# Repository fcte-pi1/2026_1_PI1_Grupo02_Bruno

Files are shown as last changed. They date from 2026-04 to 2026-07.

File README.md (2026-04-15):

# Template PI1

Esse é o _template_ de repositório para ser utilizado pelos grupos de PI1 para organizar seu projeto. O _template_ é dividido em pastas, onde cada parte do projeto deve ser armazenada. Os arquivos a serem armazenados incluem documentação, código-fonte, arquivos de CAD, esquemáticos, arquivos de simulação de circuitos, e dados.

A organização e a correta utilização do repositório do projeto serão considerados na avaliação do grupo. Dessa forma, recomenda-se que *todos os membros* do grupo leiam as instruções deste repositório, aprendam a a utilizar o git (caso ainda não saibam) e também que o grupo combine uma estratégia de como irão utilizar o repositório em conjunto. Dessa forma não deixem de utilizar todas as ferramentas que o GitHub oferece, incluindo branchs, PRs, revisões, issues, calendários, dentre outros.

Lembrem sempre de evitar enviar arquivos muito grandes (>5MB). No caso de vídeos e outros arquivos pesados que são necessários, armazenar o arquivo em outra plataforma e colocar aqui apenas o _link_.

> [!IMPORTANT]
> A estrutura de pastas do projeto não reflete a divisão de equipes. Os membros podem e devem trabalhar nas diferentes pastas a depender da necessidade do projeto.

## Utilização

1. Crie o repositório do projeto utilizando a nomenclatura padrão no formato: `<ano>.<semestre>_PI1_Grupo<n>_<professor>`. Como um exemplo, um nome formado corretamente seria `2026.1_PI1_Grupo1_Diogo`. 

2. Crie uma equipe do projeto com a mesma nomenclatura do repositório porém com o sufixo `_Equipe`, como `2026.1_PI1_Grupo1_Diogo_Equipe`, e solicite, caso necessário, que a equipe tenha permissão de escrita no repositório do projeto.

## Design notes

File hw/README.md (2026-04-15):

# _Hardware_

Esta pasta deverá armazenar arquivos referentes a:

- Simulações de circuitos eletrônicos (alimentação, sensores, atuadores etc.): [Qucs](https://qucs.sourceforge.net/), [QSPICE](https://www.qorvo.com/design-hub/design-tools/interactive/qspice), [Fritzing](https://fritzing.org/), dentre outros.
- Esquemáticos de circuitos: [KiCad](https://www.kicad.org/), Qucs, QSPICE.
- Diagramas de bloco: [Canva](https://www.canva.com/pt_br/), [TikZ](https://tikz.net/).
- _Datasheets_ de componentes eletrônicos, microcontroladores, _shields_ Arduino, motores etc.
- Testes tabelados de circuitos: arquivos CSV, Excel.
- Imagens PNG e JPEG de resultados práticos: fotos de testes reais, gráficos de resultados etc.
- Outros arquivos referentes ao _hardware_ do projeto.

> [!WARNING]
> **Não acrescente código-fonte a esta pasta.** O código desenvolvido para microcontroladores e SOCs ([Arduino](https://www.arduino.cc/), [ESP32](https://www.espressif.com/), [Raspberry Pi](https://www.raspberrypi.com/)) deverá ser armazenado na pasta [src/firmware](https://github.com/fcte-pi1/template/tree/main/src/firmware) deste repositório.

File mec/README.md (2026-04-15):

# _Mecânica e Estruturas_

Esta pasta deverá ser utilizada para armazenar arquivos relativos ao projeto estrutural, mecanismos, materiais, estudos aerodinâmicos, equações dinâmicas, construção e manufatura, impressão 3D, e correlatos.

Os arquivos a serem incluídos, são, dentre outros:
- Arquivos CAD de peças e montagens (FCStd, STEP, etc). 
- Desenhos técnicos (pdf, etc).
- Arquivos de impressão 3D (STL, etc).
- Imagens rasterizadas e vetorizadas (eps, pdf, svg, etc).
- Documentos e estudos realizados para o projeto (markdown, LaTeX, etc).

Durante o projeto, os grupos são encorajados a realizarem estudos para o projeto de estruturas, mecanismos, aerodinamica, dentre outros, e muitos desses estudos não caberão no relatório a ser entregue. Esses estudos podem ser colocados também nessa pasta, preferencialmente utilizando markdown (.md) para facilitar a leitura em ambiente web. Lembre-se que você pode utilizar equações em formato LaTeX no markdown e não deixe de utilizar links para o material de referencia que utilizaram. Estudos bem realizados contarão de maneira positiva na avaliação das equipes, porém lembre-se que não é permitida a utilização de IA, e que esse material deve ser principalmente útil à equipe.

> [!WARNING]
> Não acrecente arquivos da parte de hardware eletrônico aqui, como arquivos de KiCAD. Estes devem ser salvos na pasta [hw](https://github.com/fcte-pi1/template/tree/main/hw) deste repositório.

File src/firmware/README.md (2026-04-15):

# _Firmware_
Esta pasta deverá armazenar arquivos referentes a:

- Código-fonte para microcontroladores e SOCs: [Arduino](https://www.arduino.cc/), [ESP32](https://www.espressif.com/), [Raspberry Pi](https://www.raspberrypi.com/), dentre outros.
- Projetos de organização destes códigos, caso utilize IDEs: [Arduino IDE](https://www.arduino.cc/en/software/), [Visual Studio](https://visualstudio.microsoft.com/pt-br/downloads/) etc.
- Arquivos de configuração: ```CMakeLists.txt``` se for usar [CMake](https://cmake.org/download/), ```Makefile``` se for usar [make](https://www.cs.colby.edu/maxwell/courses/tutorials/maketutor/) etc.

Evite incluir:
- Artefatos de compilação: os arquivos de saída compilados (binários, arquivos objeto, .hex, .elf) devem ser gerados pelo processo de compilação e não incluídos no repositório.
- Arquivos temporários/específicos do sistema operacional: Arquivos como .DS_Store (macOS) ou arquivos de configuração do editor (a menos que esteja usando uma configuração compartilhada como .editorconfig).
- Configurações pessoais: Arquivos de configuração locais específicos da máquina do desenvolvedor.

> [!WARNING]
> **Não acrescente arquivos referentes a _hardware_ nesta pasta.** Eles deverão ser armazenados na pasta [hw](https://github.com/fcte-pi1/template/tree/main/hw) deste repositório.

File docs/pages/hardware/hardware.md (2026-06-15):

# Descrição de Hardware

O núcleo de hardware do projeto RataTuring é responsável pela **percepção do ambiente**, **controle de movimentação** e **transmissão de telemetria** em tempo real. Para atender aos requisitos do Micromouse, foram selecionados componentes capazes de oferecer processamento eficiente, leitura precisa do ambiente e controle confiável dos atuadores.

## 1. Microcontrolador

A unidade central de controle do robô é a **ESP32 WROOM-32E de 38 pinos**, escolhida por oferecer quantidade suficiente de portas GPIO *(General Purpose Input/Output)* para integração simultânea com encoders magnéticos, sensores infravermelhos e chave DIP de configuração.

Além da maior disponibilidade de interfaces físicas, a ESP32 atende às necessidades computacionais do projeto ao oferecer arquitetura de **32 bits**, frequência de operação de até **240 MHz**, conectividade **Wi‑Fi e Bluetooth integradas** e suporte à execução paralela por meio de **dois núcleos de processamento**.

Essa arquitetura permite que o robô execute simultaneamente tarefas como processamento de sensores, controle de movimentação, mapeamento do labirinto e transmissão de telemetria em tempo real para o sistema web.

A utilização da versão de 38 pinos também demandou um planejamento cuidadoso do mapeamento das GPIOs, especialmente devido à presença de portas associadas à memória flash interna do chip, garantindo estabilidade no funcionamento do sistema embarcado.

## 2. Sensores de Percepção

Para a detecção de paredes e leitura do ambiente, foram selecionados **sensores infravermelhos (IR)**. Essa escolha foi motivada pela baixa latência de leitura e pela adequação ao ambiente controlado do Micromouse, onde as superfícies do labirinto possuem características visuais padronizadas.

Os sensores IR permitem detectar obstáculos por meio da emissão e reflexão de luz infravermelha, possibilitando a estimativa da distância até paredes próximas. Foram definidos **três sensores** reflexivos TCRT5000, posicionados à esquerda, à frente e à direita do robô.

## 3. Sistema de Locomoção e Odometria

O sistema de movimentação utiliza **motores DC N20 com encoders magnéticos integrados**, responsáveis tanto pela propulsão quanto pela medição do deslocamento do robô.

Os encoders geram pulsos elétricos proporcionais à rotação do eixo do motor, permitindo ao microcontrolador calcular com precisão a **distância percorrida** e a **velocidade das rodas**. Essas informações são fundamentais para o rastreamento da posição do robô no labirinto, especialmente em trechos onde os sensores infravermelhos não conseguem fornecer referências suficientes do ambiente.

Assim, os encoders complementam o sistema de percepção, fornecendo dados essenciais para o mapeamento e navegação.

## 4. Sistema de Alimentação

O robô é alimentado por uma **bateria LiPo de 7,4 V**, cuja tensão é superior à suportada pela ESP32. Para adequar a alimentação do sistema, optou-se pela utilização de um **conversor DC-DC Step-Down (Buck Converter LM2596)**.

A escolha do conversor buck ocorreu devido à sua **alta eficiência energética**, reduzindo a tensão da bateria sem dissipar grande parte da energia em forma de calor, diferentemente de reguladores lineares ou divisores resistivos. Essa característica contribui para maior autonomia energética do robô e maior estabilidade operacional durante a execução da corrida.

Além disso, para atender ao requisito de monitoramento energético em tempo real, foi implementado um **circuito divisor de tensão**, permitindo que a ESP32 realize a leitura segura da tensão da bateria e envie essas informações ao sistema de telemetria.

## 5. Controle dos Motores

O acionamento dos motores é realizado por meio da **ponte H TB6612FNG**, responsável por intermediar a comunicação entre a ESP32 e os motores DC.

Esse componente foi escolhido em substituição ao modelo L298N devido ao **menor tamanho físico**, **menor resistência interna** e **maior eficiência energética**, resultando em maior estabilidade de tensão e melhor desempenho no controle dos motores.

Além disso, a TB6612FNG suporta frequências elevadas de controle PWM, permitindo ajustes mais precisos de velocidade e reduzindo vibrações ou perda de torque em baixas velocidades, aspecto essencial para a navegação precisa em um labirinto Micromouse.

## 6. Considerações Gerais

A arquitetura de hardware proposta foi definida de forma a atender aos requisitos funcionais do projeto, principalmente aqueles relacionados à **navegação autônoma**, **mapeamento do labirinto**, **precisão de movimento** e **transmissão de telemetria em tempo real**. A combinação entre ESP32, sensores IR, encoders, conversor buck e ponte H fornece uma base robusta para o funcionamento do sistema embarcado do RataTuring.

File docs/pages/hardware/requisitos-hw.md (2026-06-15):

# Requisitos de Hardware

| Código | Descrição |
| --- | --- |
| **RF-ELEC-01**  | **Redução e Estabilização de Tensão para a Lógica:** Medição estável de **3.3V (±0.1V)** nos terminais de saída do módulo. |
| **RF-ELEC-02**  | **Monitoramento de Tensão da Bateria via ADC:** O Serial Monitor do ESP32 deve exibir a voltagem real da bateria com margem de erro de **±0.2V**. |
| **RF-ELEC-03**  | **Interface de Segurança e Proteção de Polaridade:** O sistema deve ligar/desligar via chave física e bloquear a passagem de energia se a bateria for conectada invertida. |
| **RF-ELEC-04**  | **Detecção de Barreiras Físicas via Infravermelho (IR):** O hardware deve gerar uma variação de tensão entre **0V e 3.3V** proporcional à distância da parede. |
| **RF-ELEC-05**  | **Mapeamento da Curva de Resposta dos Sensores:** O firmware deve converter os valores do ADC (**0–4095**) em distância linear (**cm**) com precisão de **±1 cm** na faixa de **3 cm a 15 cm**. |
| **RF-ELEC-06**  | **Definição e Mapeamento de Pinos (Pinout) do ESP32:** Conexão física de todos os periféricos (sensores e motores) sem conflitos de GPIOs ou funções especiais. |
| **RF-ELEC-07**  | **Controle de Direção e Potência dos Motores:** Acionamento bi-direcional das rodas utilizando a tensão da bateria sob comando lógico do ESP32. |
| **RF-ELEC-08**  | **Modulação de Velocidade por Largura de Pulso (PWM):** Variação linear da rotação dos motores controlada pelo software entre **10% e 100%** da potência. |
| **RNF-ELEC-01** | **Filtragem de Interferência Eletromagnética (EMI):** A leitura do sensor no Serial Monitor não deve oscilar mais que **2%** quando os motores estiverem em carga máxima. |

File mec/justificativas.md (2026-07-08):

# Núcleo de Estruturas & Mecânica — Micromouse

Este documento detalha o desenvolvimento mecânico, os requisitos de projeto, a seleção de materiais e o processo de montagem tanto do chassi do robô quanto do labirinto de testes, enfatizando o caráter multidisciplinar integrado à eletrônica e alimentação.

---

## Abordagem Multidisciplinar & Requisitos de Design

O design mecânico do Micromouse foi inteiramente concebido sob a ótica da **multidisciplinaridade**. O chassi não atua apenas como suporte físico, mas sim como uma interface otimizada para acomodar de forma compacta e estratégica os subsistemas das outras áreas:

* **Arquitetura em Dois Andares:** * **Primeiro Andar (Inferior):** Dedicado exclusivamente à acomodação dos componentes de alimentação e potência (baterias e fiação pesada), rebaixando o centro de gravidade.
    * **Segundo Andar (Superior):** Dedicado à proteção e fixação das placas de circuito, sensores e hardware de processamento.
* **Locomoção e Manobrabilidade:** Utiliza um sistema de direção diferencial com **2 motores N20 individuais e independentes** (um para cada roda) e **1 roda boba (*caster*)** posicionada na parte frontal. Essa configuração permite que o robô gire em torno do seu próprio eixo, economizando tempo e espaço.
* **Restrição Geométrica:** O robô foi projetado para caber perfeitamente e se mover de forma fluida dentro de uma única célula do labirinto (**18x18 cm**), garantindo folga nas curvas e evitando colisões com as paredes.

---

## Especificações Técnicas e Dimensões

### O Chassi
* **Material:** Impressão 3D (Polímero).
* **Dimensões Gerais:** 100 mm de comprimento × 70 mm de largura.
* **Pilares de Sustentação:** 16 mm de altura (espaçamento entre os andares).
* **Rodas:** 43 mm de diâmetro × 18 mm de largura.

### O Labirinto (Concepção Modular)
O labirinto de testes adota uma filosofia de **modularidade** para montagem e desmontagem rápida, crucial para os testes práticos da equipe de software. Ele foi projetado para mitigar interferências nos sensores ópticos e de distância do robô:
* **Dimensões da Base Principal:** 795 × 795 mm.
* **Malha da Base:** Matriz contendo **25 furos** para acoplamento dinâmico.
* **Células:** Padrão de 18 × 18 cm cada.
* **Paredes e Pilares:** 6 cm de altura.
* **Materiais e Acabamento Visual (Requisito Sensorial):**
    * **Base:** Feita em MDF com pintura em **preto fosco**, evitando reflexos ópticos indesejados que comprometeriam a leitura dos sensores de linha/distância.
    * **Paredes:** Feitas em MDF com acabamento em **branco** e o **topo em vermelho**, garantindo o contraste necessário para a navegação do robô.
    * **Pilares de Encaixe:** Impressos em 3D para acoplamento firme na base.

---

## Processo de Montagem

### Montagem do Robô:
1.  **Fixação dos Motores:** Os dois motores N20 são posicionados no primeiro andar e firmados utilizando **clamps parafusados**, o que elimina folgas mecânicas e garante rigidez durante acelerações bruscas.
2.  **Acoplamento das Rodas:** As rodas principais são conectadas diretamente aos eixos dos motores N20 e a roda boba é posicionada na seção frontal inferior.
3.  **União dos Andares:** O segundo andar é fixado sobre o primeiro utilizando os pilares de sustentação de 16 mm.

### Montagem do Labirinto:
1.  As paredes de MDF possuem um design com **extremidades dentadas**.
2.  Esses dentes se acoplam diretamente aos **pilares de encaixe em 3D**.
3.  O conjunto (parede + pilar) é encaixado por pressão na **matriz de 25 furos** da base de MDF preta, permitindo alterar a configuração do labirinto facilmente entre as sessões de teste.

---

## Análise Estrutural Computacional (ANSYS)

Para garantir a confiabilidade do robô antes da fabricação dos componentes físicos, o modelo tridimensional do chassi foi submetido a uma **Análise Estrutural Numérica no software ANSYS**. 
O estudo focou na simulação estática e dinâmica para verificar o comportamento do polímero impresso sob a ação das cargas reais do projeto (peso das baterias, placas eletrotécnicas, forças de aceleração e frenagem dos motores N20). A análise validou que a espessura das paredes e a disposição dos pilares de 16 mm suportam os esforços operacionais com margem de segurança adequada, evitando trincas ou deformações excessivas durante as manobras.

---

## Localização dos Arquivos no Repositório

Toda a modelagem 3D (arquivos `.CATPart`), simulações, arquivos de impressão e detalhamentos estão centralizados na pasta de mecânica do projeto:

```text
📂 Mec/
├── 📂 CAD Labirinto/           # Modelagem tridimensional do labirinto modular em CATIA
├── 📂 Desenho Técnico/         # Desenhos técnicos detalhados com as cotas e dimensões formais
├── 📂 Robô/                    # Modelos finais do chassi (CATPart), análises estruturais (ANSYS) e Resultados.
└── 📂 STL para impressão 3D/   # Arquivos de impressão (STL)

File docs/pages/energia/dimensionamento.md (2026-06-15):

# Dimensionamento Energético

## 1. Introdução

Dimensionar e implementar um sistema de alimentação que garanta uma autonomia mínima de 30 minutos de operação contínua, utilizando baterias que possam ser recarregadas totalmente em menos de duas horas.

---

## 2. Levantamento de Carga (Especificação dos Componentes)

A Tabela 1 detalha todos os componentes eletrônicos e eletromecânicos integrados ao robô, seus respectivos consumos nominais de corrente, tensões de operação e estimativa de energia consumida.

### Tabela 1: Especificação de consumo dos componentes do Micromouse

| Componente | Especificação | Quantidade | Corrente (mA) | Tensão | Energia (J) |
| :--- | :--- | :---: | :---: | :---: | :---: |
| Microcontrolador | ESP32 WROOM 32E | 1 | 117 (com WiFi) | 3.3V | 695,16 |
| Buck Converter | LM2596 | 1 | 21 | 7.4V | 279,72 |
| Sensores IR | TCRT5000 | 3 | 20 | 3.3V | 356,40 |
| Ponte H | TB6612FNG | 1 | 5 | 3.3V | 29,70 |
| Motor N20 - A | | 1 | 53 | 6V | 572,40 |
| Motor N20 - B | | 1 | 46 | 6V | 496,80 |

---

## 3. Cálculo da Corrente Total ($I_{total}$)

Para determinar o consumo total no pior cenário operacional (todos os componentes atuando simultaneamente e em carga máxima), aplica-se a seguinte equação de soma das correntes:

$$I_{total} = I_{esp32\_wifi} + I_{buck} + (3 \times I_{ir}) + I_{ponteH} + I_{motorA} + I_{motorB}$$

Substituindo os valores nominais fornecidos pelo relatório técnico:

$$I_{total} = 117\text{ mA} + 21\text{ mA} + (3 \times 20\text{ mA}) + 5\text{ mA} + 53\text{ mA} + 46\text{ mA}$$
$$I_{total} = 117 + 21 + 60 + 5 + 53 + 46$$
$$I_{total} = 242\text{ mA}$$

---

## 4. Cálculo de Autonomia do Sistema

Para a validação real do comportamento elétrico no solo (labirinto), adota-se uma margem de segurança severa com fator de correção de $2\times$ sobre o consumo medido em vazio, resultando em uma taxa de queda projetada de $0,96\text{ V/h}$. O tempo de uso contínuo estimado ($T_{autonomia}$) considerando a janela útil de tensão de $2,4\text{ V}$ da bateria é calculado por:

$$T_{autonomia} = \frac{2,4\text{ V}}{0,96\text{ V/h}}$$

$$T_{autonomia} \approx \mathbf{2,5\text{ horas}}$$

Convertendo o tempo estimado para minutos:

$$T_{autonomia} = 2,5 \times 60 = \mathbf{150\text{ minutos}}$$

---

## 5. Conclusão

Com o consumo total de **242 mA**, é estimado para o arranjo de baterias de 1200 mAh uma autonomia de aproximadamente **150 minutos** (cerca de 2 horas e meia) de funcionamento contínuo pro micromouse. Considerando também que a bateria escolhida é recarregável e pode ser recarregada completamente em um período de até duas horas.

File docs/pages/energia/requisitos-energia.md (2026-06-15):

# Requisitos de Energia
| Código | Descrição |
|---|---|
| **RF-ENER-01** | A fonte de energia deve ser altamente compacta e apresentar uma excelente relação peso/potência, garantindo que o chassi permaneça leve. |
| **RF-ENER-02** | O sistema de alimentação deve utilizar baterias adequadas para suprir a demanda por um período contínuo de 20 a 30 minutos em regime de testes. |
| **RF-ENER-03** | O conjunto de baterias deve garantir energia suficiente para os componentes e sustentar os picos elétricos do arranque dos motores. |
| **RF-ENER-04** | O projeto deve integrar um BMS como interface de proteção contra descarga profunda, sobrecarga e curtos-circuitos. |

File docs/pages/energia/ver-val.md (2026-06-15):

# Relatório de Testes de Verificação e Validação: Consumo Energético

## 1. Objetivo

Avaliar o perfil de descarga da alimentação do micromouse sob diferentes regimes de operação.

O sistema utiliza uma bateria composta por 2 células de 3,7 V ligadas em série, resultando em uma tensão nominal de 7,4 V e capacidade de 1200 mAh. O intuito é estimar a autonomia do projeto e garantir que a carga suporte a conclusão do labirinto sem interrupções por queda de tensão durante as avaliações da disciplina.

---

## 2. Metodologia de Verificação (Ensaios em Bancada)

Para mapear o consumo de energia dos diferentes subsistemas, a queda de tensão da bateria foi monitorada via multímetro durante dois ensaios práticos, com duração de 1 hora cada.

### 2.1 Teste 1 – Sistema Lógico em Standby (Perfil Quiescente)

Apenas o microcontrolador (ESP32) e o circuito regulador (Buck Converter) foram mantidos ativos, sem acionamento dos motores.

**Resultado:** Queda de 0,16 V/h.

**Análise:** Consumo mínimo e estável, demonstrando alta eficiência da eletrônica de controle e do regulador chaveado quando não há demanda de potência.

### 2.2 Teste 2 – Atuadores em Vazio (Perfil Dinâmico)

Sistema lógico ativo (com comunicação Wi‑Fi) em conjunto com o acionamento dos motores em velocidade máxima, porém com o robô suspenso em bancada (rodas girando no ar, sem contato com o solo).

**Resultado:** Queda de 0,48 V/h.

**Análise:** O dreno de energia triplicou em relação ao estado de repouso (3×), confirmando que a carga motriz é a variável dominante no consumo do sistema.

---

## 3. Medição de Corrente e Comparação Teórico-Prática

### 3.1 Mapeamento de Corrente (Ensaios Isolados)

- **Sistema Lógico (Sem Wi‑Fi):** 83 mA (ESP) + 21 mA (Buck) = 104 mA
- **Sistema Lógico (Com Wi‑Fi):** 117 mA (ESP) + 21 mA (Buck) = 138 mA
- **Sistema de Tração (Vazio):** 53 mA (Motor A) + 46 mA (Motor B) + 5 mA (Ponte H) = 104 mA

Corrente total de pico:

```text
Itotal = 138 mA + 104 mA = 242 mA
```

### 3.2 Modelagem Teórica vs. Medição Empírica

Considerando a capacidade nominal da bateria de 1200 mAh:

```text
Tempo Teórico = 1200 mAh / 242 mA ≈ 4,95 horas
```

Janela útil de tensão da bateria:

```text
8,4 V - 6,0 V = 2,4 V
```

Taxa teórica esperada:

```text
Taxa Teórica = 2,4 V / 4,95 h ≈ 0,484 V/h
```

| Comparação | Valor |
|---|---|
| Modelo Matemático | 0,484 V/h |
| Teste Prático | 0,480 V/h |

### 3.3 Potência e Consumo Energético Total

```text
Ptotal = 7,4 V × 0,242 A ≈ 1,79 W
```

Energia disponível:

```text
E = 8,88 Wh
```

Autonomia energética:

```text
Tempo Teórico = 8,88 Wh / 1,79 W ≈ 4,95 horas
```

**Conclusão da comparação:** O ensaio prático validou o modelo matemático de consumo. A variação registrada é explicada pela incerteza natural do equipamento de medição. O consumo global inferior a 2 W confirma a adequação energética do hardware.

---

## 4. Validação e Projeções para a Apresentação Final

Os dados obtidos em bancada verificam o comportamento elétrico isolado do hardware.

Contudo, para a validação real no labirinto, deve-se considerar que o Teste 2 representa um cenário otimista (rodas livres de atrito).

No chão, os motores demandarão maior corrente elétrica para vencer a inércia, deslocar a massa total do robô e superar o atrito da superfície. Esse esforço mecânico adicional exigirá mais torque, acelerando a taxa de descarga em relação aos 0,48 V/h medidos no ar.

---

## 5. Análise de Atendimento das Demandas Energéticas

### 5.1 Demanda de Autonomia Mínima

O robô necessita de autonomia suficiente para realizar múltiplas tentativas de resolução do labirinto durante a avaliação oficial da disciplina, sem necessidade de recargas constantes.

### 5.2 Margem de Segurança Aplicada

Considerando um cenário real severo com o dobro do consumo aferido no ar:

```text
0,96 V/h = 2 × 0,48 V/h
```

Autonomia estimada:

```text
Autonomia = 2,4 V / 0,96 V/h ≈ 2,5 horas (150 minutos)
```

### 5.3 Status de Atendimento

Os testes documentam que o arranjo de baterias escolhido (1200 mAh, 2S) atende com ampla folga térmica e elétrica às necessidades do projeto, mitigando riscos de reinicialização do microcontrolador por subtensão.

---

## 6. Conclusão

Os ensaios em bancada cumpriram os requisitos de verificação energética.

O mapeamento do consumo permitiu estabelecer um limite inferior confiável de descarga e calcular o tempo de persistência em operação.

Com uma autonomia projetada superior a 2 horas em regime de esforço mecânico, a integridade elétrica do micromouse está validada para a apresentação final da disciplina.

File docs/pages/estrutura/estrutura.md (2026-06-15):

# Estruturas: Chassi e Labirinto

## 1. Visão Geral do Projeto

O chassi e o labirinto do Micromouse foram modelados no CATIA, priorizando **compactação, estabilidade, modularidade e desempenho em navegação autônoma**.

O chassi foi desenvolvido com **direção diferencial**, utilizando duas rodas de tração independentes, permitindo curvas rápidas e rotações no próprio eixo. Já o labirinto foi projetado de forma **modular**, facilitando montagem, desmontagem e criação de diferentes cenários de teste.

---

## 2. Escolha dos Materiais

Após análise comparativa entre acrílico, MDF e impressão 3D, optou-se pela **impressão 3D** para o chassi devido aos seguintes fatores:

### Justificativas principais:

* **Maior liberdade geométrica**, permitindo peças complexas e encaixes específicos;
* **Boa resistência mecânica** para o uso esperado;
* **Baixo custo do material**, especialmente considerando que não haverá cobrança de produção.

---

## 3. Sistema de Locomoção (Rodas)

Foi adotada uma configuração de **duas rodas de tração independentes + roda boba frontal**.

### Justificativas:

* Permite o robô **girar sobre o próprio eixo**;
* Facilita curvas rápidas e precisas;
* Reduz tempo de navegação no labirinto;
* Melhora a eficiência em espaços reduzidos.

Essa arquitetura é amplamente utilizada em robôs Micromouse por oferecer **alta manobrabilidade**.

---

## 4. Chassi

| Característica | Chassi Novo |
| --- | ---: |
| Comprimento | 100 mm |
| Largura | 70 mm |
| Altura dos pilares | 16 mm |

---

## 5. Centro de Gravidade e Momento de Inércia

Foi realizada uma análise física no CATIA para verificar estabilidade.

### Resultado principal:

O **centro de gravidade ficou próximo ao centro geométrico do robô**, indicando **boa distribuição de massa**.

### Benefícios:

* Menor oscilação em curvas;
* Mais estabilidade em aceleração e frenagem;
* Melhor comportamento em mudanças bruscas de direção.

Além disso, houve **redução dos momentos de inércia**, o que significa:

### Impacto prático:

* O robô exige **menos torque dos motores** para girar;
* Faz curvas mais rápidas;
* Tem respostas mais ágeis nas correções de trajetória;
* Melhor desempenho em testes de Micromouse.

A redução da altura dos pilares foi essencial para concentrar a massa mais próxima do plano central do robô.

---

## 6. Projeto do Labirinto

O labirinto foi desenvolvido pensando em **precisão dimensional, modularidade e confiabilidade dos sensores**.

### Estrutura:

* Base em **MDF preto fosco**;
* Pilares produzidos em **impressão 3D**;
* Sistema de encaixe modular;
* Matriz de furos para diferentes configurações do percurso.

### Justificativas importantes:

#### 6.1 Base Preto Fosco

Escolhida para reduzir reflexos de luz.

**Benefício:**
Evita interferência nos sensores do robô, melhorando a leitura das paredes e do solo.

---

#### 6.2 Tolerância de Encaixe

Foi criada uma folga entre furos e pinos (**0,5 mm**).

**Benefício:**

* Facilita montagem;
* Compensa pequenas imperfeições da impressão 3D;
* Evita esforço excessivo e deformações.

---

#### 6.3 Estabilidade Mecânica

A espessura da estrutura foi escolhida para evitar vibração das paredes.

**Benefício:**
Evita erros de mapeamento do robô durante deslocamentos rápidos.

---

#### 6.4 Modularidade

O sistema permite **alterar rapidamente a configuração do labirinto**.

**Benefícios:**

* Criar vários cenários de teste;
* Validar o algoritmo BFS;
* Repetir experimentos com diferentes layouts.

Furos não utilizados serão nivelados com peças impressas em 3D para evitar irregularidades no piso e erros de odometria.

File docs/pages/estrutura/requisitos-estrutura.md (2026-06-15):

# Requisitos de Estruturas
| Código | Descrição |
|---|---|
| **RF-LAB-01** | O Labirinto deve ter paredes de 1,2 cm de espessura e 5 cm de altura. |
| **RF-LAB-02** | O Labirinto deve ter tamanho 4x4 células. |
| **RF-LAB-03** | As paredes devem ser brancas no topo e vermelhas/pretas nas laterais. O chão deve ser preto fosco para evitar reflexos indesejados nos sensores ópticos. |
| **RF-ESTR-01** | A estrutura deve garantir que o robô suporte o próprio peso e consiga se mover. |
| **RF-ESTR-02** | O chassi deve suportar a montagem de sensores de forma que não haja interferência estrutural na leitura das paredes do labirinto. |
| **RF-ESTR-03** | A estrutura deve garantir que as rodas mantenham contato constante ao solo. |
| **RF-ESTR-04** | O robô deve estar contido em um quadrado de 16 cm × 16 cm. |
| **RNF-ESTR-01** | O material deve ser de baixo custo, resistente e de fácil fabricação. |

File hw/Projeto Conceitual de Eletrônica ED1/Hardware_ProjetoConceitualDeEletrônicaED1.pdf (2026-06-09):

# 4.3 Hardware

A parte que forma o núcleo de Hardware no projeto do Micromouse é relacionado à percepção do mundo e controle de suas ações.
Foi escolhido para atuar como sistema central do robô o microcontrolador ESP32 DevKit V1. Inicialmente, houve dúvida entre ele e o Arduíno Leonardo, porém optou-se por aquele pela sua capacidade de operar com frequências maiores (240MHz) e trabalho com 32 bits. Logo, é possível realizar mais operações se comparado ao Arduino em questão, que trabalha em (16 MHz) e 8 bits. Afinal, essas métricas afetam diretamente a capacidade do microcontrolador fazer cálculos complexos, enquanto o Arduino vai de 0 a 255 por vez, a ESP32 DevKit V1 processa palavras de 32 bits em um clock, assim, o código irá ser executado com uma rapidez consideravelmente maior, característica que se mostra fundamental no requisito que demanda a transmissão de dados de telemetria em tempo real via Wi-fi para um sistema web.
Além disso, o Micromouse precisa simultaneamente: enviar dados de telemetria pro sistema web e comunicar com os demais componentes, recebendo e enviando comandos para eles. Com isso em mente, a ESP32 DevKit V1 tem dois núcleos, o Application CPU e o Protocol CPU, este tem como função transmitir as informações para o website e aquele cuidar das demandas do mundo real. Em decorrer disso, a ESP32 DevKit V1 é capaz de separar as tarefas e fazê-las ao mesmo tempo e, por esse motivo, deve se mostrar mais adequada perante a necessidade de mapear o labirinto, andar nele e ter Wi-Fi e bluetooth integrados, facilitando a visualização do labirinto e seu mapeamento e evitando travar o funcionamento do próprio Micromouse ao mandar os dados por Wi-fi.
Os sensores têm como objetivo realizar a leitura do ambiente e, após pesquisar a fundo, foi decidido que o sensor infravermelho (IR) será uma opção mais coerente se. Projeto Conceitual do Produto 27 comparada ao sensor laser. Isso se deve ao fato de que o sensor IR tem uma latência menor de dados, assim, ao identificar uma parede, o microcontrolador será avisado o mais rápido possível e terá tempo de reagir adequadamente a essa informação. Além disso, devido ao ambiente de uso do Micromouse ser controlado e o labirinto não possuir variações de cores, o uso do sensor IR não apresenta nenhuma contraindicação. Mas para entender melhor o porquê disso é crucial compreender como o sensor IR funciona: ele atira uma ’luz invisível’ e mede o quanto dessa luz é refletida de volta, desse modo, a monocromacia do labirinto permite que o programa de software possa seguir um padrão de lógica ao medir os valores entregues pelos sensores e se torne possível o cálculo da distância. Com isso, depois de escolhidos, é importante determinar quantos serão utilizados. Após discutir com a equipe de software, foi decidido que serão usados quatro sensores: dois frontais angulados, para ser capaz de identificar curvas de forma antecipada, e dois, para manter-se centralizado nos corredores do labirinto.
Para complementar o sistema de percepção, o RataTuring utiliza motores DC N20 equipados com encoders magnéticos embutidos. Mas por que esses sensores são importantes para o Micromouse? Ao imaginá-lo percorrendo um corredor longo, sem paredes na frente perto o suficiente para a leitura eficaz da luz refletida pelos sensores IR, fica evidente a necessidade de medir a distância percorrida por ele para ser possível mapear quantas células do labirinto passaram. Dessa maneira, os encoders leem a rotação do eixo do motor e geram pulsos elétricos a cada fração de giro, depois, o microcontrolador recebe e contabiliza esses pulsos digitais em tempo real. Assim, essa conversão direta de movimento mecânico em dados digitais permite que o sistema calcule, com alta precisão, a velocidade atual das rodas e a distância exata percorrida, informações essenciais para o mapeamento e o rastreamento da posição do robô no labirinto
O próximo impasse foi como regular o nível de tensão da bateria de Polímero de Lítio (LiPo) que oferece 7.4V. Isso se mostra necessário pois a ESP32 DevKit V1 só suporta 5V como alimentação.
Inicialmente, foi cogitado o uso de dois resistores simples organizados num divisor de tensão para resolver esse problema de maneira simples e barata. Porém, o problema está justamente na matemática do divisor de tensão:

V

out = V
in

·

R
2
R

1+R
2

(4.3)

que só funciona perfeitamente quando nada está consumindo energia daquele fio do meio. Entretanto, o ESP 32 não é um componente passivo, ele é dinâmico. Quando ele está apenas usando o núcleo Application CPU, consome pouca energia (por volta de 40 miliamperes). Mas, no momento em que ele liga o Protocol CPU para enviar a telemetria do trajeto, ele já puxa um pico gigantesco de energia (até 400 miliamperes).
Na prática, quando o ESP 32 puxa essa corrente, ele atua como se fosse um terceiro resistor invisível que muda de valor o tempo todo. Dessa maneira, a voltagem que era 3.3V despenca instantaneamente para 1.5V ou menos. Assim, sem energia suficiente, provavelmente o microcontrolador vai apagar e reiniciar sozinho, ou seja, o micromouse morreria no meio do labirinto.
Em seguida, pensei em um diodo Zener (junto com um resistor) ou um regulador linear tradicional que conseguiriam manter a tensão estável em 3.3V mesmo quando o microcontrolador puxar muita energia. Porém, o problema deles é como eles fazem isso: eles transformam o excesso de energia em forma de calor. No RataTuring, houve o receio de que isso viraria um desastre por estar drenando e desperdiçando o consumo de bateria do Micromouse apenas para gerar calor no chassi do carrinho e fazendo com que a bateria durasse poucos minutos.
Finalmente, foi acertado o uso de um módulo Buck Converter LM2596 para baixar essa energia. Assim, um Buck Converter (ou conversor Step-Down) é uma válvula redutora de pressão inteligente. De maneira que, ao invés de simplesmente frear a energia e transformar o excesso em calor, como um resistor (o que desperdiçaria a bateria do Micromouse muito rápido), ele liga e desliga a energia milhares de vezes por segundo. Logo, isso reduz a voltagem média que sai do outro lado de forma extremamente eficiente, fazendo a bateria durar muito mais tempo.
No âmbito de bateria, o requisito do projeto onde se faz necessário haver a leitura do nível da bateria a todo momento em tempo real, fez crucial a implementação de um circuito divisor de tensão. Ele irá contar com dois resistores organizados de modo para que a ESP 32 consiga ler a voltagem da bateria sem queimar, cumprindo o requisito de enviar esse dado para a telemetria.
Em última instância, foi discutida a necessidade de uma Ponte H para fazer a comunicação entre os sinais da ESP32 DevKit V1 com os motores DC N20. Afinal, dessa maneira, os sinais da ESP32 DevKit V1 irão ser suficientemente ampliados, dado que ela funciona em uma voltagem muito menor do que os motores e, caso eles tentassem se comunicar sem a ponte H, a ESP32 DevKit V1 poderia ser danificada por não ter o sinal suficiente para alimentá-los. Quanto ao modelo, a preferência foi do modelo TB6612FNG ao invés do modelo L298N, pois seu tamanho e sua resistência interna são bem menores. Logo, culminará em maior estabilidade de tensão, desse modo, assegurando confiabilidade maior, suportando frequências de até 100 kHz e permitindo o controle de velocidade sem vibração do motor ou perda de força em baixas velocidades.

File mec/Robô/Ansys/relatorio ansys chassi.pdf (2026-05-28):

# Project

First Saved | Tuesday, May 26, 2026
Last Saved | Wednesday, May 27, 2026
Product Version | 2026 R1
Save Project Before Solution | No
Save Project After Solution | No
Project | Page 1 of 23
file:///C:/Users/Mateus/AppData/Roaming/Ansys/v261/Mechanical_Report/Mechanical_Report.htm | 28/05/2026

Project | Page 2 of 23

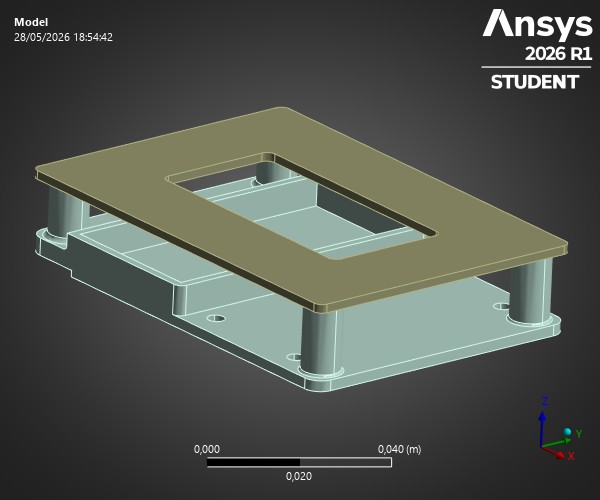
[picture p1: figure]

# Contents

l Units

l Model (A4)
¡ Geometry Imports
n Geometry Import (A3)
¡ Geometry
n Parts
¡ Materials
¡ Coordinate Systems
¡ Connections
n Contacts
n Contact Region
¡ Mesh
¡ Static Structural (A5)
n Analysis Settings
n Acceleration
n Loads
n Solution (A6)
n Solution Information
n Results

l Material Data
¡ PLA

# Units

TABLE 1
Unit System | Metric (m, kg, N, s, V, A) Degrees rad/s Celsius
Angle | Degrees
Rotational Velocity | rad/s
Temperature | Celsius
Project | Page 3 of 23

# Model (A4)

TABLE 2
Model (A4) > Geometry Imports

TABLE 3
Model (A4) > Geometry Imports > Geometry Import (A3)
Object Name | Geometry Imports
State | Solved
Object Name | Geometry Import (A3)
State | Solved
Definition
Source | C:\Users\Mateus\OneDrive\Documentos\UnB\4 sem\PI\Chassi\Final chassis\chassis.stp
Type | Step
Basic Geometry Options
Solid Bodies | Yes
Surface Bodies | Yes
Line Bodies | No
Parameters | Independent
Parameter Key | ANS;DS
Attributes | No
Named Selections | No
Material Properties | No
Advanced Geometry Options
Use Associativity | Yes
Coordinate Systems | No
Reader Mode Saves Updated File | No
Use Instances | Yes
Smart CAD Update | Yes
Compare Parts On Update | No
Analysis Type | 3-D
Mixed Import Resolution | None
Import Facet Quality | Source
Clean Bodies On Import | No
Stitch Surfaces On Import | Program Tolerance
Stitch Tolerance | 0,0000001
Decompose Disjoint Geometry | Yes
Project | Page 4 of 23

Enclosure and Symmetry Processing | Yes

## Geometry

TABLE 4
Model (A4) > Geometry
Object Name | Geometry
State | Fully Defined
Definition
Source | C:\Users\Mateus\OneDrive\Documentos\UnB\4 sem\PI\Chassi\Final chassis\chassis.stp
Type | Step
Length Unit | Millimeters
Element Control | Program Controlled
Display Style | Body Color
Bounding Box
Length X | 0,1 m
Length Y | 7,e-002 m
Length Z | 2,05e-002 m
Properties
Volume | 3,4711e-005 m³
Mass | 4,3041e-002 kg
Scale Factor Value | 1,
Statistics
Bodies | 2
Active Bodies | 2
Nodes | 6897
Elements | 3228
Mesh Metric | None
Update Options
Assign Default Material | No
Basic Geometry Options
Solid Bodies | Yes
Surface Bodies | Yes
Line Bodies | No
Parameters | Independent
Parameter Key | ANS;DS
Attributes | No
Project | Page 5 of 23

TABLE 5
Model (A4) > Geometry > Parts
Named Selections | No
Material Properties | No
Advanced Geometry Options
Use Associativity | Yes
Coordinate Systems | No
Reader Mode Saves Updated File | No
Use Instances | Yes
Smart CAD Update | Yes
Compare Parts On Update | No
Analysis Type | 3-D
Mixed Import Resolution | None
Import Facet Quality | Source
Clean Bodies On Import | No
Stitch Surfaces On Import | Program Tolerance
Decompose Disjoint Geometry | Yes
ID_GeometryPrefProcessPhysicsDefinition | No
Enclosure and Symmetry Processing | Yes
Object Name | Part2|PartBody | 1st level|PartBody
State | Meshed
Graphics Properties
Visible | Yes
Transparency | 1
Definition
Suppressed | No
Stiffness Behavior | Flexible
Coordinate System | Default Coordinate System
Reference Temperature | By Environment
Treatment | None
Material
Assignment | PLA
Nonlinear Effects | Yes
Thermal Strain Effects | Yes
Bounding Box
Length X | 0,1 m
Project | Page 6 of 23

TABLE 6
Model (A4) > Materials
Length Y | 7,e-002 m
Length Z | 7,2e-003 m | 1,85e-002 m
| Properties
Volume | 1,0729e-005 m³ | 2,3981e-005 m³
Mass | 1,3304e-002 kg | 2,9737e-002 kg
Centroid X | -5,e-003 m | -8,959e-003 m
Centroid Y | 3,9581e-014 m | 4,5509e-013 m
Centroid Z | 1,939e-002 m | 3,2278e-003 m
Moment of Inertia Ip1 | 7,0995e-006 kg·m² | 1,4703e-005 kg·m²
Moment of Inertia Ip2 | 1,3915e-005 kg·m² | 2,8909e-005 kg·m²
Moment of Inertia Ip3 | 2,0994e-005 kg·m² | 4,2853e-005 kg·m²
Statistics
Nodes | 2115 | 4782
Elements | 925 | 2303
Mesh Metric | None
Object Name | Materials
State | Fully Defined
Statistics
Materials | 2
Material Assignments | 0

## Coordinate Systems

TABLE 7
Model (A4) > Coordinate Systems > Coordinate System
Object Name | Global Coordinate System
State | Fully Defined
Definition
Type | Cartesian
Coordinate System ID | 0,
Origin
Origin X | 0, m
Origin Y | 0, m
Origin Z | 0, m
Project | Page 7 of 23

Directional Vectors
X Axis Data | [ 1, 0, 0, ]
Y Axis Data | [ 0, 1, 0, ]
Z Axis Data | [ 0, 0, 1, ]
Transfer Properties
Source
Read Only | No

## Connections

TABLE 8
Model (A4) > Connections

TABLE 9
Model (A4) > Connections > Contacts
Object Name | Connections
State | Fully Defined
Auto Detection
Generate Automatic Connection On Refresh Yes Transparency
Enabled Yes
Statistics
Contacts | 1
Active Contacts | 1
Joints | 0
Active Joints | 0
Beams | 0
Active Beams | 0
Bearings | 0
Active Bearings | 0
Springs | 0
Active Springs | 0
Body Interactions | 0
Active Body Interactions | 0
Object Name | Contacts
State | Fully Defined
Definition
Project | Page 8 of 23

TABLE 10
Model (A4) > Connections > Contacts > Contact Regions

Connection Type Contact
Scope
Scoping Method | Geometry Selection
Geometry | All Bodies
Auto Detection
Tolerance Type | Slider
Tolerance Slider | 0,
Tolerance Value | 3,0944e-004 m
Use Range | No
Face/Face | Yes
Face-Face Angle Tolerance | 75, °
Face Overlap Tolerance | Off
Cylindrical Faces | Include
Face/Edge | No
Edge/Edge | No
Priority | Include All
Group By | Bodies
Search Across | Bodies
Statistics
Connections | 1
Active Connections | 1
Object Name | Contact Region
State | Fully Defined
Scope
Scoping Method | Geometry Selection
Contact | 17 Faces
Target | 12 Faces
Contact Bodies | Part2|PartBody
Target Bodies | 1st level|PartBody
Protected | No
Definition
Type | Bonded
Scope Mode | Automatic
Behavior | Program Controlled
Project | Page 9 of 23

Trim Contact | Program Controlled
Trim Tolerance | 3,0944e-004 m
Contact APDL Name
Target APDL Name
Suppressed | No
Display
Element Normals | No
Advanced
Formulation | Program Controlled
Small Sliding | Program Controlled
Detection Method | Program Controlled
Penetration Tolerance | Program Controlled
Elastic Slip Tolerance | Program Controlled
Normal Stiffness | Program Controlled
Update Stiffness | Program Controlled
Pinball Region | Program Controlled
Geometric Modification
Contact Geometry Correction | None
Target Geometry Correction | None

## Mesh

TABLE 11
Model (A4) > Mesh
Object Name | Mesh
State | Solved
Display
Display Style Use Geometry Setting Defaults
Physics Preference | Mechanical
Element Order | Program Controlled
Element Size | Default (6,1887e-003 m)
Sizing
Mesh Sizing | Uniform
Bounding Box Diagonal | 0,12377 m
Average Surface Area | 3,1354e-004 m²
Minimum Edge Length | 3,1416e-004 m
Project | Page 10 of 23

# Static Structural (A5)

TABLE 12
Model (A4) > Analysis

Quality
Check Mesh Quality | Yes, Errors
Error Limits | Aggressive Mechanical
Target Element Quality | Default (0,1)
Smoothing | Medium
Mesh Optimization | No
Mesh Metric | None
Inflation
Use Automatic Inflation | None
Inflation Option | Smooth Transition
Transition Ratio | 0,272
Maximum Layers | 5
Growth Rate | 1,2
Inflation Algorithm | Pre
Inflation Element Type | Wedges
View Advanced Options | No
Advanced
Number of CPUs for Parallel Part Meshing | Program Controlled
Straight Sided Elements | No
Rigid Body Behavior | Dimensionally Reduced
Triangle Surface Mesher | Program Controlled
Topology Checking | Yes
Pinch Tolerance | Default (5,5699e-004 m)
Generate Pinch on Refresh | No
Auto-Map Fillets | No
Automatic Methods
Sheet Body Method | Prime Quad Dominant
Sweepable Body Method | Sweep
Statistics
Nodes | 6897
Elements | 3228
Show Detailed Statistics | No
Project | Page 11 of 23

TABLE 13
Model (A4) > Static Structural (A5) > Analysis Settings
Object Name | Static Structural (A5)
State | Solved
Definition
Physics Type | Structural
Analysis Type | Static Structural
Solver Target | Mechanical APDL
Options
Environment Temperature | 22, °C
Generate Input Only | No
Object Name | Analysis Settings
State | Fully Defined
Step Controls
Number Of Steps | 1,
Current Step Number | 1,
Step End Time | 1, s
Auto Time Stepping | Program Controlled
Maximum Iterations Per Substep | Program Controlled
Solver Controls
Solver Type | Program Controlled
Weak Springs | Off
Solver Pivot Checking | Program Controlled
Large Deflection | Off
Inertia Relief | Off
Quasi-Static Solution | Off
Rotordynamics Controls
Coriolis Effect | Off
Restart Controls
Generate Restart Points | Program Controlled
Retain Files After Full Solve | No
Combine Restart Files | Program Controlled
Nonlinear Controls
Newton-Raphson Option | Program Controlled
Force Convergence | Program Controlled
Moment Convergence | Program Controlled
Project | Page 12 of 23

TABLE 14
Model (A4) > Static Structural (A5) > Accelerations
Displacement Convergence | Program Controlled
Rotation Convergence | Program Controlled
Line Search | Program Controlled
Stabilization | Program Controlled
Advanced
Inverse Option | No
Contact Split (DMP) | Program Controlled
Output Controls
Output Selection | None
Stress | Yes
Back Stress | No
Strain | Yes
Contact Data | Yes
Nonlinear Data | No
Nodal Forces | No
Volume and Energy | Yes
Euler Angles | Yes
General Miscellaneous | No
Contact Miscellaneous | No
Store Results At | All Time Points
Result File Options
Result File Compression | Program Controlled
| Analysis Data Management
Solver Files Directory | C:\Users\Mateus\OneDrive\Documentos\UnB\4 sem\PI\Chassi\chassi ansys_files\dp0\SYS\MECH\
Future Analysis | None
Scratch Solver Files Directory
Save MAPDL db | No
Contact Summary | Program Controlled
Delete Unneeded Files | Yes
Nonlinear Solution | No
Solver Units | Active System
Solver Unit System | mks
Object Name | Acceleration
State | Fully Defined
Project | Page 13 of 23

FIGURE 1
Model (A4) > Static Structural (A5) > Acceleration

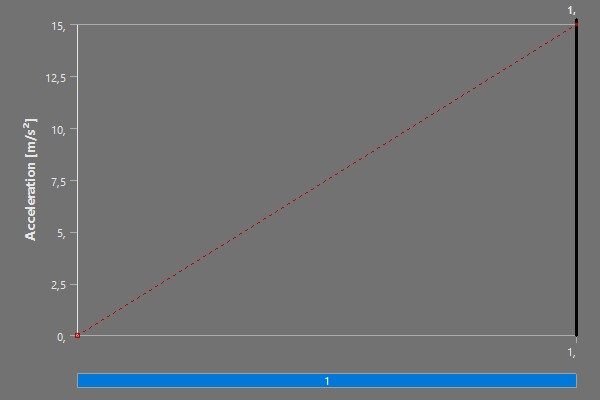
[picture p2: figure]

TABLE 15
Model (A4) > Static Structural (A5) > Loads

Scope
Geometry All Bodies
Definition
Define by | Vector
Magnitude | 15, m/s² (ramped)
Direction | Defined
Suppressed | No
Object Name | Displacement | Fixed Support | Force | Force 2
Project | Page 14 of 23

FIGURE 2
Model (A4) > Static Structural (A5) > Displacement
State | Fully Defined
Scope
Scoping Method | Geometry Selection
Geometry | 2 Faces | 8 Faces | 1 Face
Definition
Type | Displacement | Fixed Support | Force
Define by | Components | | Vector
Coordinate System | Global Coordinate System
X Component | Free
Y Component | Free
Z Component | 0, m (ramped)
Suppressed | No
Applied By | | | Surface Effect
Magnitude | | 0,5635 N (ramped) | 0,98 N (ramped)
Direction | | Defined
Project | Page 15 of 23

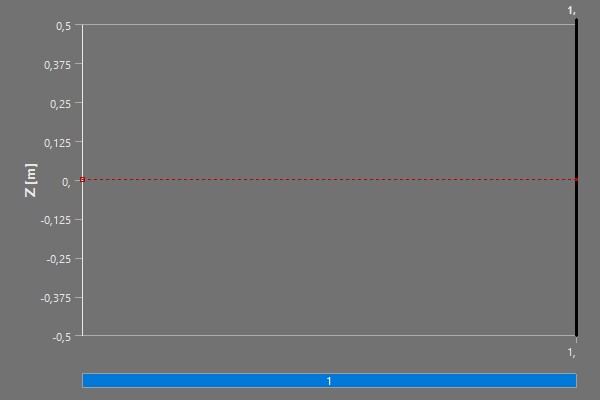
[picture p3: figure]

FIGURE 3
Model (A4) > Static Structural (A5) > Force
Project | Page 16 of 23

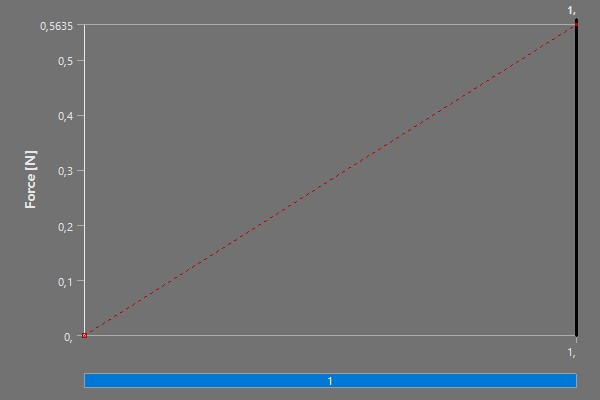
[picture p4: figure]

FIGURE 4
Model (A4) > Static Structural (A5) > Force 2
Project | Page 17 of 23

## Solution (A6)

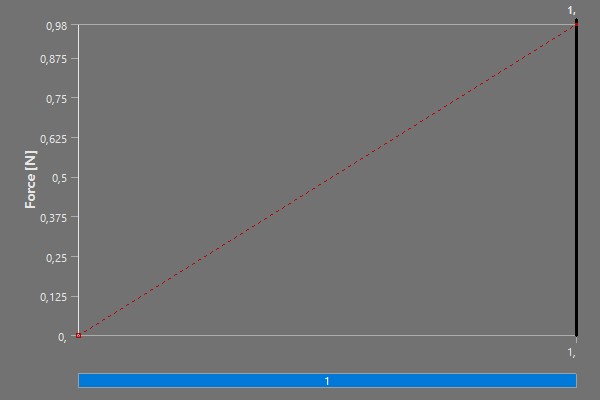
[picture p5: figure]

TABLE 16
Model (A4) > Static Structural (A5) > Solution
Object Name | Solution (A6)
State | Solved
Adaptive Mesh Refinement
Max Refinement Loops | 1,
Refinement Depth | 2,
Information
Status | Done
MAPDL Elapsed Time | 17,205 s
MAPDL Memory Used | 218, MB
Project | Page 18 of 23

TABLE 17
Model (A4) > Static Structural (A5) > Solution (A6) > Solution Information

TABLE 18
Model (A4) > Static Structural (A5) > Solution (A6) > Results

MAPDL Result File Size 2,5 MB Post Processing
Beam Section Results | No
On Demand Stress/Strain | No
Object Name | Solution Information
State | Solved
Solution Information
Solution Output | Solver Output
Newton-Raphson Residuals | 0
Identify Element Violations | 0
Update Interval | 2,5 s
Display Points | All
FE Connection Visibility
Activate Visibility | Yes
Display | All FE Connectors
Draw Connections Attached To | All Nodes
Line Color | Connection Type
Visible on Results | No
Line Thickness | Single
Display Type | Lines
Object Name | Total Deformation | Equivalent Stress
State | Solved
Scope
Scoping Method | Geometry Selection
Geometry | All Bodies
Definition
Type | Total Deformation | Equivalent (von-Mises) Stress
By | Time
Display Time | Last
Separate Data by Entity | No
Calculate Time History | Yes
Project | Page 19 of 23

FIGURE 5
Model (A4) > Static Structural (A5) > Solution (A6) > Total Deformation

Identifier
Suppressed | No
Results
Minimum | 0, m | 16,755 Pa
Maximum | 1,0418e-005 m | 1,6446e+005 Pa
Average | 1,0428e-006 m | 12822 Pa
Minimum Occurs On | 1st level|PartBody
Maximum Occurs On | Part2|PartBody | 1st level|PartBody
Information
Time | 1, s
Load Step | 1
Substep | 1
Iteration Number | 1
Integration Point Results
Display Option | Averaged
Average Across Bodies | No
Project | Page 20 of 23

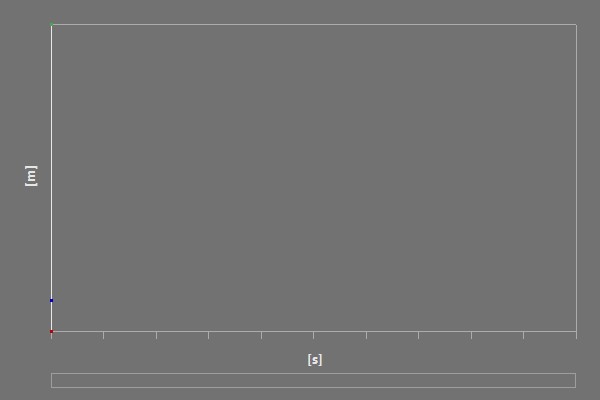
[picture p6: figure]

TABLE 19
Model (A4) > Static Structural (A5) > Solution (A6) > Total Deformation

FIGURE 6
Model (A4) > Static Structural (A5) > Solution (A6) > Equivalent Stress
Time [s] | Minimum [m] | Maximum [m] | Average [m]
1, | 0, | 1,0418e-005 | 1,0428e-006
Project | Page 21 of 23

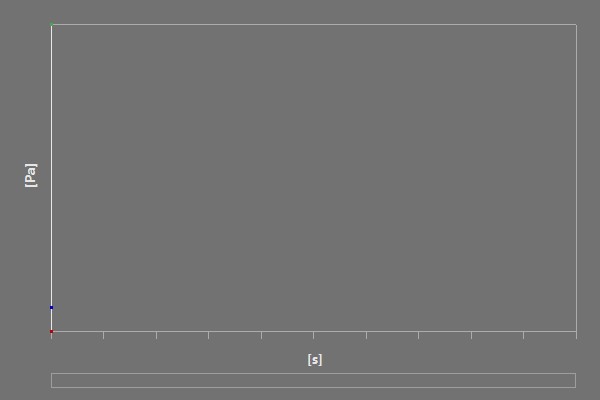
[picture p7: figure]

TABLE 20
Model (A4) > Static Structural (A5) > Solution (A6) > Equivalent Stress

# Material Data

Time [s] | Minimum [Pa] | Maximum [Pa] | Average [Pa]
1, | 16,755 | 1,6446e+005 | 12822

## PLA

TABLE 21
PLA > Constants
Density | 1240, kg m^-3
Project | Page 22 of 23

TABLE 22
PLA > Color

TABLE 23
PLA > Isotropic Elasticity

TABLE 24
PLA > Tensile Yield Strength
Red | Green | Blue
235, | 222, | 222,
Young's Modulus Pa | Poisson's Ratio | Bulk Modulus Pa | Shear Modulus Pa | Temperature C
3,5e+009 | 0,36 | 4,1667e+009 | 1,2868e+009

Tensile Yield Strength Pa
5,e+007
Project | Page 23 of 23

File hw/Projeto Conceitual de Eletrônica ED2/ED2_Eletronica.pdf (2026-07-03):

# 4.3 Hardware

## 4.3.1 Visão Geral

Para esta segunda etapa do projeto, o núcleo de eletrônica consolidou a transição entre o planejamento conceitual de componentes e a implementação física da arquitetura. Assim, o foco desta entrega concentrou-se na segurança lógica no mapeamento de portas, calibração experimental e testes unitários e de integração dos componentes.
Inicialmente, é importante ressaltar que uma mudança de escopo fundamental para o sucesso do projeto foi a substituição do microcontrolador previsto no primeiro ponto de controle. Isso se deu por conta de dois fatores principais: pinos insuficientes e atraso na entrega. O modelo cogitado anteriormente, ESP32 DEVKIT V1, de 30 pinos foi descartado devido a um atraso na postagem da encomenda em decorrência da falta do produto no estoque. Entretanto, isso se mostrou benéfico, pois ficou evidente que essa placa não seria adequada. Assim, foi escolhida a ESP32 WROOM 32E de 38 pinos devido à necessidade de expandir a quantidade de portas GPIO (General Purpose Input/Output) disponíveis. Com o avanço do projeto, a demanda por canais dedicados para encoders magnéticos de alta velocidade, múltiplos sensores infravermelhos e chave DIP ultrapassou o limite físico da placa antiga. Assim, a versão de 38 pinos garantiu a quantidade necessária para o sistema de controle, embora tenha exigido um estudo mais rigoroso de isolamento das trilhas de memória flash integradas ao chip para evitar travamentos indesejados.

## 4.3.2 Sistema de Alimentação

O circuito inicia na bateria de Polímero de Lítio (LiPo) de duas células (2S), cujos terminais físicos foram soldados diretamente nos contatos de leitura e balanceamento (B+,BM e B −) da placa de circuito de proteção BMS (Battery Management System) pelo núcleo de energia. Por sua vez, a saída de carga controlada que alimenta o projeto é extraída exclusivamente dos terminais de potência P + e P − da própria BMS.

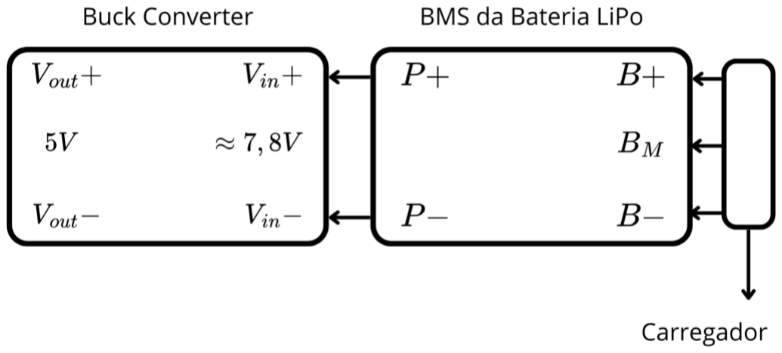
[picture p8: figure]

Figura 1 – Esquemático de Alimentação.

Além disso, a fim de evitar o consumo constante e a descarga parasitária da bateria quando o robô estiver em repouso, foi integrado ao projeto um interruptor geral do tipo chave alavanca SPST (Single Pole Single Throw). Esta chave foi posicionada estrategicamente em série na linha positiva de alta corrente, interceptando o fluxo elétrico entre o terminal P + da BMS e a entrada de tensão positiva (Vin +) do módulo regulador Buck Converter (LM2596). O terminal negativo (P −) conecta-se de forma direta ao barramento comum de terra do conversor (Vin −).

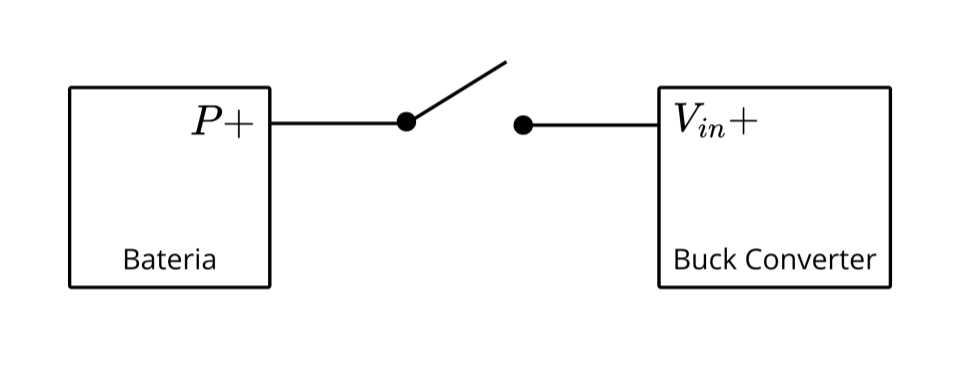
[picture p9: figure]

Figura 2 – Esquemático do Interruptor Geral.

O módulo Buck Converter LM2596 utilizado possui um diferencial técnico muito conveniente para a bancada: um voltímetro digital integrado com um botão seletor físico de alternância. Dessa maneira, ao pressionar este botão, o operador consegue chavear instantaneamente a leitura do display entre a tensão de entrada (vinda da bateria através do P + , variando entre ≈ 6.4V e 8.4V ) e a tensão regulada de saída (ajustada para 5.0V

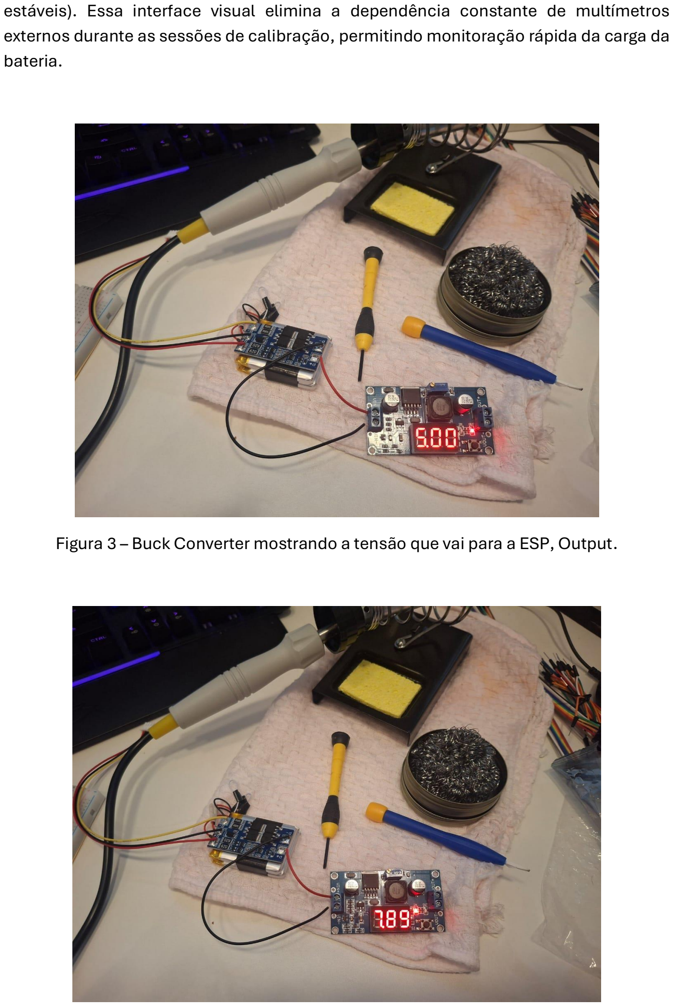
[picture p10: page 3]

estáveis). Essa interface visual elimina a dependência constante de multímetros externos durante as sessões de calibração, permitindo monitoração rápida da carga da bateria.

Figura 3 – Buck Converter mostrando a tensão que vai para a ESP, Output.

Figura 4 – Buck Converter mostrando a tensão da bateria, Input.

## 4.3.3 Mapeamento do microcontrolador

O diagrama de conexões do microcontrolador foi mapeado de forma a blindar o sistema contra falhas de inicialização e perdas de dados sensoriais durante a comunicação sem fio.
Inicialmente, foram mapeados os pinos críticos associados ao barramento de comunicação interna da memória flash do chip e pinos de configuração de boot (Strapping Pins) e todos eles foram permanentemente isolados e marcados como proibidos no projeto. São eles: EN, CLK, SD0, SD1, SD2, SD3, P15, P2, P0, P12, P5, RX e TX. Afinal, conectar qualquer atuador ou sensor a essas linhas poderia forçar a placa a entrar em modos de gravação incorretos durante a energização, impedindo a execução correta do firmware do Micromouse.
Ademais, a arquitetura interna do circuito impresso divide as entradas analógicas em dois blocos: ADC1 e ADC2. Entretanto, há uma restrição física de fábrica na qual o canal ADC2 compartilha o mesmo circuito integrado utilizado pelo rádio Wi-Fi. Consequentemente, no momento em que o RataTuring ativa o protocolo de rede para transmitir dados de telemetria em tempo real para a interface web, todas as leituras de pinos ligados ao ADC2 são congeladas e param de funcionar. Desse modo, a fim de contornar este problema e impedir que o robô fique cego enquanto transmite dados, todas as leituras críticas foram mapeadas exclusivamente no canal ADC1, que opera de forma independente do Wi-Fi. São elas: leitura de carga da bateria e sensores infravermelhos.
Por fim, os 9 pinos GPIOs (General Purpose Input/Output) restantes são classificados como seguros no datasheet do microcontrolador pois possuem estabilidade bidirecional plena. Essa característica permite que atuem tanto como saídas de potência digital confiáveis (acionamento da Ponte H) quanto como entradas de alta velocidade e baixa latência (leitura dos Encoders magnéticos e da Chave DIP de estratégia), assegurando a estabilidade operacional do sistema sem riscos de flutuação lógica ou travamento de boot.

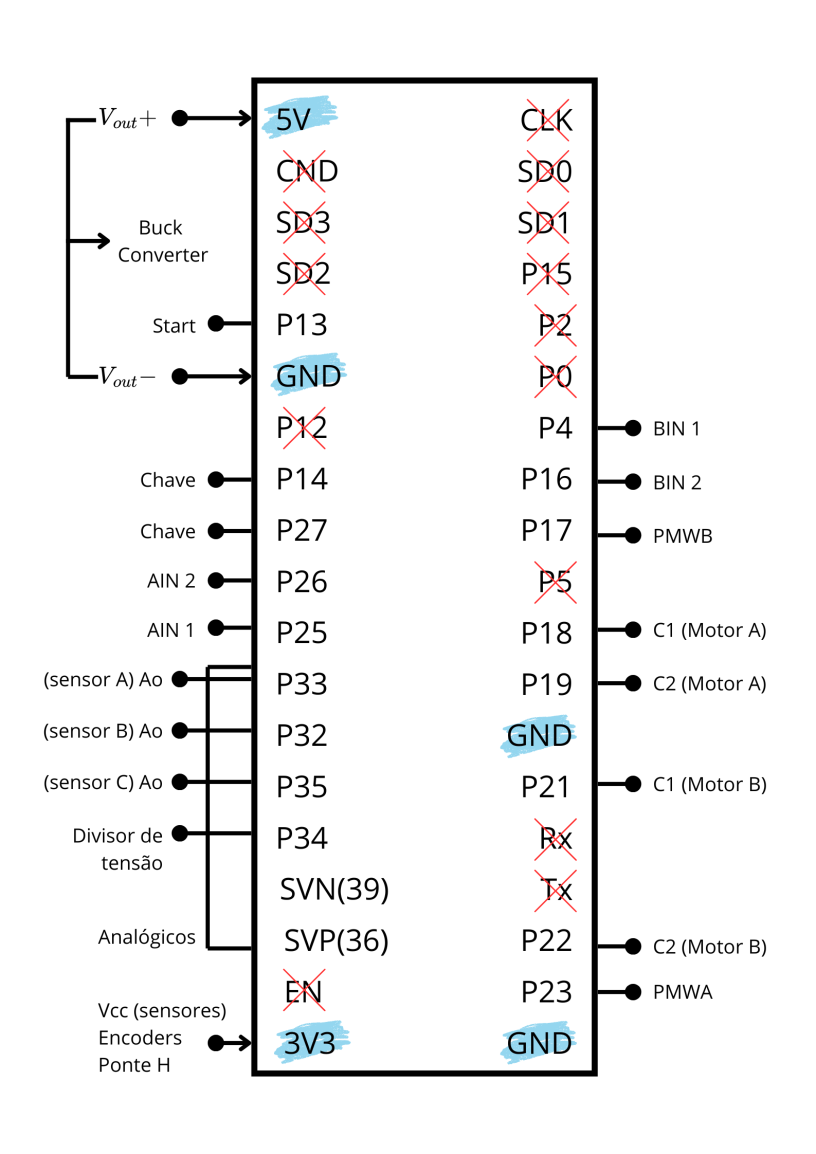
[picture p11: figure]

Figura 5 – Esquemático do mapeamento da ESP

## 4.3.4 Monitoramento da Bateria

Para cumprir o requisito de telemetria em tempo real sem queimar as portas do microcontrolador, foi projetado um circuito divisor de tensão resistivo. Como os pinos analógicos do processador possuem uma tolerância máxima absoluta de entrada de 3.3V, injetar os 8.4V diretos da bateria totalmente carregada resultaria na queima instantânea do silício. Dessa maneira, o circuito divisor emprega dois resistores fixos dispostos em série: (R1): 10kΩ, conectado diretamente à linha de tensão positiva vinda da bateria (Vin +) mas depois do interruptor geral a fim de evitar gastos quando o sistema não estiver em uso, e (R2): 4.7kΩ, conectado ao barramento comum de terra (GND). O ponto de junção central entre R1 e R2 fornece a tensão atenuada (Vout), que é conectada diretamente ao pino analógico da placa.

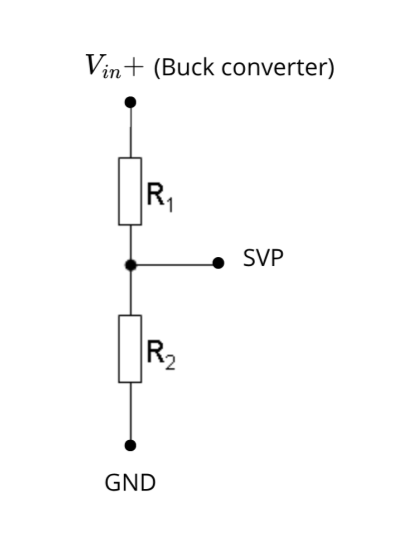
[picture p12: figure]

Figura 6 – Esquemático do Divisor de Tensão.

A relação matemática que rege o comportamento deste circuito é definida pela equação clássica do divisor resistivo:

Vout = Vin ⋅

R2
R1 + R2

(1)

Aplicando os valores nominais para o pior cenário possível (bateria em carga máxima com 8.4V):

Vout = 8.4 ⋅

4.7kΩ
10kΩ + 4.7kΩ

Vout = 8.4 ⋅

4700
14700

≈ 2.69V

O resultado de aproximadamente 2.69V comprova que a tensão enviada ao pino analógico permanece em uma zona de extrema segurança, bem abaixo do limite de 3.3V. Essa calibração oferece uma margem de proteção confortável contra picos de tensão transitórios.

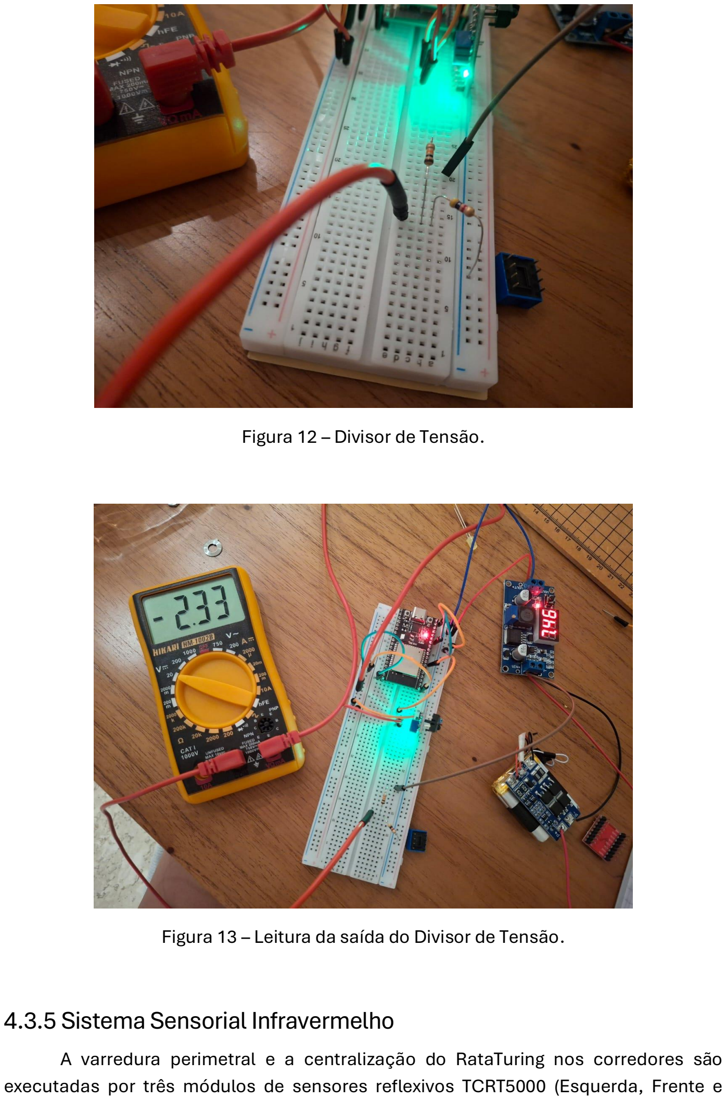
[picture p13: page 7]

Figura 12 – Divisor de Tensão.

Figura 13 – Leitura da saída do Divisor de Tensão.

## 4.3.5 Sistema Sensorial Infravermelho

A varredura perimetral e a centralização do RataTuring nos corredores são executadas por três módulos de sensores reflexivos TCRT5000 (Esquerda, Frente e

Direita). Vale ressaltar, que o pino de saída digital (D0

) foi completamente removido e desconsiderado no projeto. Uma leitura do tipo liga/desliga seria ineficaz para o controle do robô, pois não permitiria calcular o quão próximo ou afastado o chassi está de uma parede. A fiação será soldada estritamente no terminal analógico (A0

), enviando o nível
de tensão variável diretamente para as portas dedicadas do canal ADC1 da ESP32.

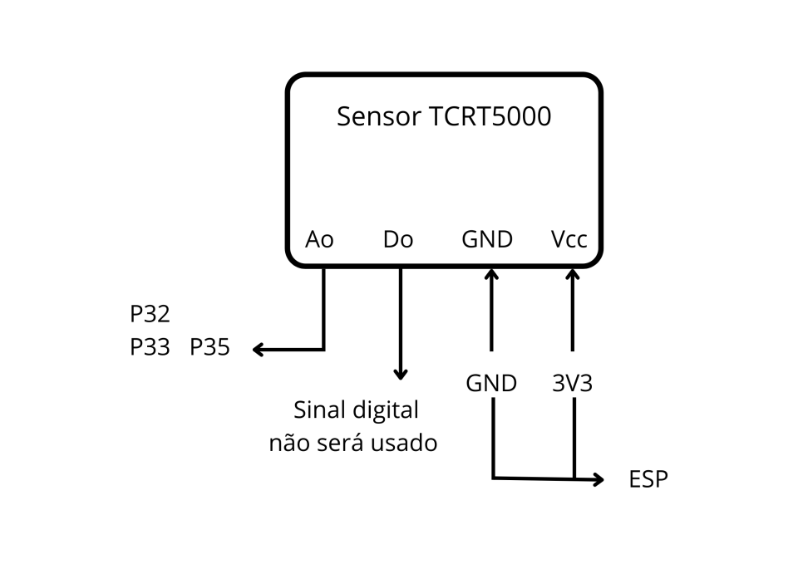
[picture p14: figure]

Figura 14 – Esquemático dos Sensores TCRT5000.

Para mapear com precisão o comportamento físico dos sensores frente à refletividade das paredes monocromáticas do labirinto, realizou-se um ensaio experimental de calibração em bancada. O comportamento dinâmico da tensão analógica em função da distância em centímetros gerou os seguintes dados de referência:

Figura 15 – Tabela de Resultado do Teste dos Sensores TCRT5000.

Os dados revelam uma curva de resposta altamente não-linear, típica de sensores baseados em fototransistores reflexivos, cujo comportamento elétrico é diretamente ditado por sua geometria óptica. Em distâncias curtas (1 cm a 3 cm), o sensor apresenta um ponto cego natural: o ângulo de reflexão da luz colide com a barreira física interna do módulo, obscurecendo o receptor e mantendo a tensão baixa. Logo, fica evidente que a sensibilidade máxima ocorre na faixa de 3 cm a 6 cm, onde a tensão salta bruscamente de 0.24V para 2.04V. Este pico repentino representa o momento de alinhamento perfeito, onde a parede recua o suficiente para refletir o feixe infravermelho de forma concentrada para dentro da lente do receptor. A partir de 7 cm, a curva entra em uma zona de saturação gradual, estabilizando-se próxima a 2.76V na distância limite de 12 cm. Esta saturação é explicada pela Lei do Inverso do Quadrado da Distância (I ∝

1
d²

); com o afastamento do obstáculo, a luz sofre dispersão espacial e a intensidade luminosa captada cai drasticamente.

## 4.3.6 Integração de Tração e Odometria: Motores, Encoders e Ponte H

O sistema de movimento e localização usa motores N20 com engrenagens para aumentar a força, encoders magnéticos (sensores que medem o giro exato das rodas) e a Ponte H que é placa que controla a direção e a energia dos motores.
A montagem foi pensada para evitar interferências elétricas e economizar as portas da placa ESP32. Afinal, motores elétricos criam ruídos e picos de tensão na fiação quando funcionam e, para evitar que atrapalhe o desempenho dos demais componentes, os fios de alta potência foram separados dos fios de sinais lógicos, dessa maneira, a energia bruta para girar os motores vem direto do Buck Converter. Já a energia mais fraca e limpa, usada para a inteligência da Ponte H e para os sensores, sai dos 3,3V da própria placa ESP32. Além disso, todos os fios negativos (GND) foram unidos em um ponto só. Isso previne falhas chamadas de "loops de terra", que são correntes indesejadas que bagunçam as leituras do robô.
Ademais, para economizar as portas da ESP32, o pino responsável por ligar e desligar a Ponte H foi conectado direto na energia de 3,3V. Assim, a Ponte H fica sempre ligada por padrão e evita o uso um pino a mais da ESP32 só para essa função.
Além disso, para o controle da velocidade das rodas, foram usados sinais PWM que são uma técnica de controle que liga e desliga a energia muito rápido para dosar a força do motor. Esses sinais foram ligados apenas em pinos digitais da zona segura, garantindo que a ordem de velocidade saia perfeita.
Por fim, o robô depende da odometria, que é o cálculo matemático da distância que ele já percorreu. Essa medida alimenta o controle PID, que é o algoritmo responsável por corrigir a rota automaticamente se o robô entortar. Desse modo, a fim de evitar a perda de medidas de distância, os encoders foram ligados a pinos que aceitam interrupções de hardware, ou seja, um comando de alerta máximo: ela obriga o processador a pausar tudo o que está fazendo para registrar o giro da roda na mesma hora. Isso garante que nenhum movimento seja perdido durante acelerações ou curvas rápidas, mantendo a posição do robô sempre exata.

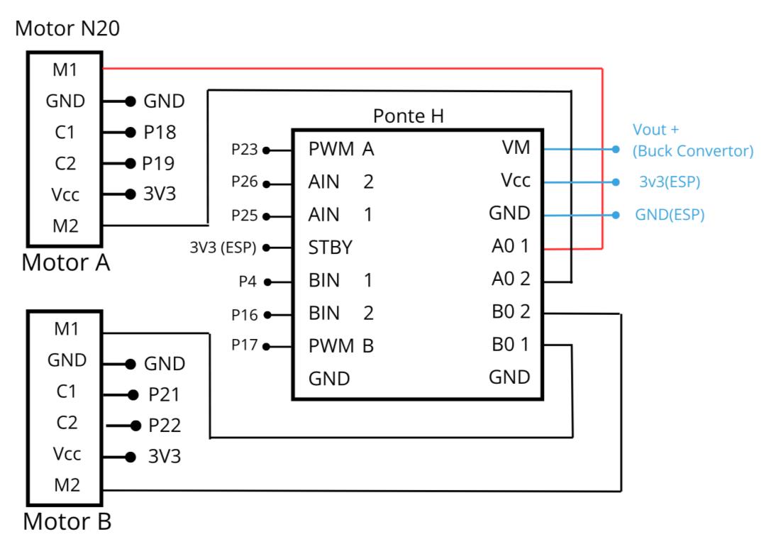
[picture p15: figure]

Figura 16 – Esquemático dos Motores, Encoders e Ponte H.

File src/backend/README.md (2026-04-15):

# _Backend_

Esta pasta deverá armazenar arquivos referentes a:

- Código-fonte da API REST: rotas, controladores, modelos e lógica de negócio.
- Arquivos de configuração do servidor: `app.py`, `server.js`, `main.go` etc., dependendo da linguagem/framework utilizado ([Flask](https://flask.palletsprojects.com/), [FastAPI](https://fastapi.tiangolo.com/), [Express](https://expressjs.com/), [Django](https://www.djangoproject.com/) etc.).
- Arquivos de definição de dependências: `requirements.txt` ou `pyproject.toml` (Python), `package.json` (Node.js), `pom.xml` (Java/Maven) etc.
- Scripts de migração e esquemas de banco de dados: arquivos `.sql`, scripts de migração ([Alembic](https://alembic.sqlalchemy.org/), [Sequelize](https://sequelize.org/) etc.) e seeds de dados para desenvolvimento.
- Arquivos de configuração de ambiente: `.env.example` com as variáveis de ambiente necessárias (nunca o `.env` real).
- Arquivos de containerização: `Dockerfile` e `docker-compose.yml`, caso o serviço seja executado em contêiner.

Evite incluir:

- Credenciais e segredos: arquivos `.env`, chaves de API, senhas, tokens de acesso ou qualquer dado sensível **nunca** devem ser versionados.
- Artefatos de build: diretórios como `__pycache__/`, `dist/`, `build/`, `.eggs/` devem ser gerados localmente e ignorados via `.gitignore`.
- Dependências instaladas: pastas como `node_modules/` ou ambientes virtuais Python (`venv/`, `.env/`) não devem ser incluídos no repositório.
- Arquivos temporários/específicos do sistema operacional: arquivos gerados automaticamente pelo sistema ou pelo gerenciador de arquivos (ex.: `*~`, `.DS_Store`, `Thumbs.db`).
> [!WARNING]
> **Não acrescente arquivos referentes ao _frontend_ nesta pasta.** Eles deverão ser armazenados na pasta [frontend](https://github.com/fcte-pi1/template/tree/main/src/frontend) deste repositório.

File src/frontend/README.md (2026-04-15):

# _Frontend_

Esta pasta deverá armazenar arquivos referentes a:

- Código-fonte da interface: componentes, páginas, estilos e lógica de apresentação, organizados conforme o framework utilizado ([React](https://react.dev/), [Vue](https://vuejs.org/), [Angular](https://angular.io/) etc.).
- Arquivos de marcação e estilo estáticos: `index.html`, arquivos `.css`, `.scss` ou `.sass` de estilização global.
- Arquivos de definição de dependências: `package.json` e `package-lock.json` (ou `yarn.lock`) com todas as bibliotecas utilizadas.
- Arquivos de configuração do bundler/toolchain: `vite.config.js`, `webpack.config.js`, `tsconfig.json` etc.
- Arquivos de configuração de ambiente: `.env.example` com as variáveis de ambiente públicas necessárias (ex.: URL base da API).
- Arquivos de containerização: `Dockerfile` e `docker-compose.yml`, caso a aplicação seja servida via contêiner.

Evite incluir:

- Dependências instaladas: a pasta `node_modules/` deve ser gerada localmente via `npm install` ou equivalente e nunca incluída no repositório.
- Artefatos de build: diretórios como `dist/`, `build/` ou `.next/` são gerados pelo processo de compilação e não devem ser versionados.
- Arquivos de configuração pessoal: arquivos como `.directory` (Linux/KDE) ou configurações locais de editor (ex.: `.vscode/settings.json`), salvo configurações compartilhadas como `.editorconfig`.
- Credenciais e segredos: arquivos `.env` com valores reais nunca devem ser versionados.

> [!WARNING]
> **Não acrescente arquivos referentes ao _backend_ nesta pasta.** Eles deverão ser armazenados na pasta [backend](https://github.com/fcte-pi1/template/tree/main/src/backend) deste repositório.

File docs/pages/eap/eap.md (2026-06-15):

Essa seção guarda a Estrutura Analítica do Projeto.

## EAP de Hardware

<p align="center">
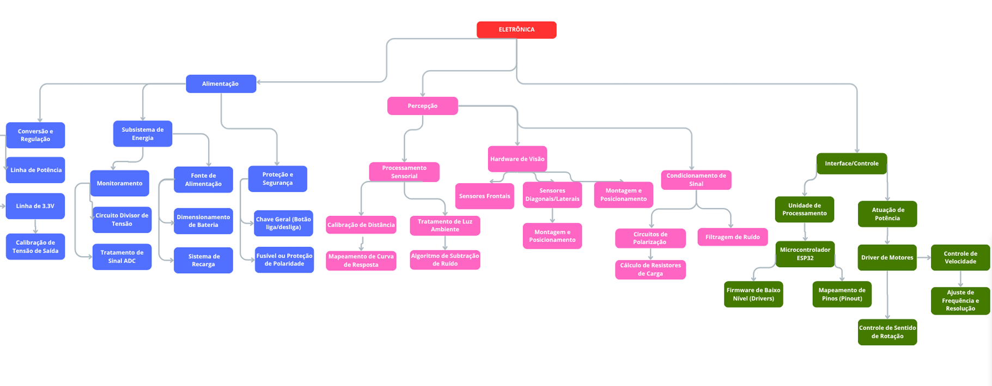
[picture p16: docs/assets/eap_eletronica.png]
  
</p>

---

## EAP de Energia

<p align="center">
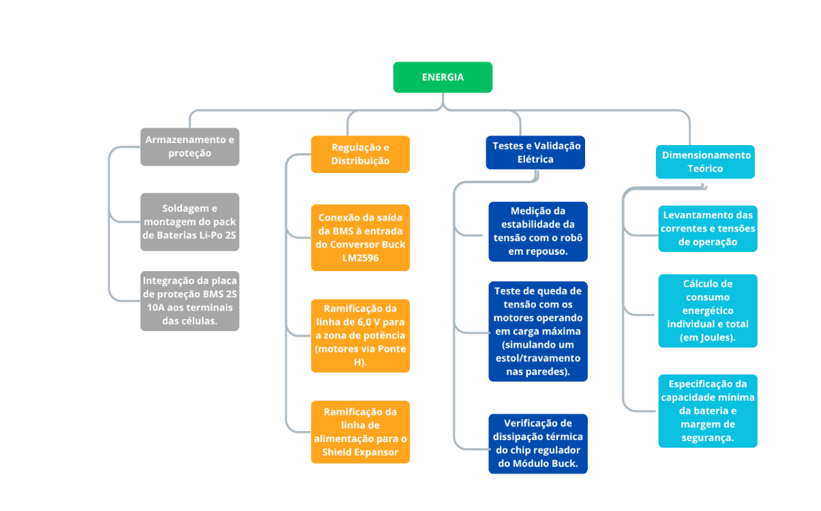
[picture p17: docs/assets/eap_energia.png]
  
</p>

---

## EAP de Estruturas

<p align="center">
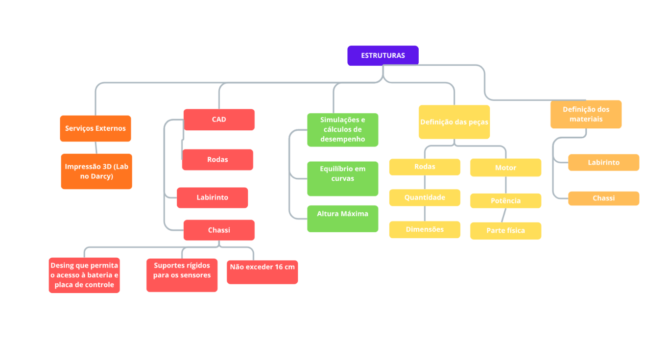
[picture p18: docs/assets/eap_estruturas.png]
  
</p>

---

## EAP de Software

<p align="center">
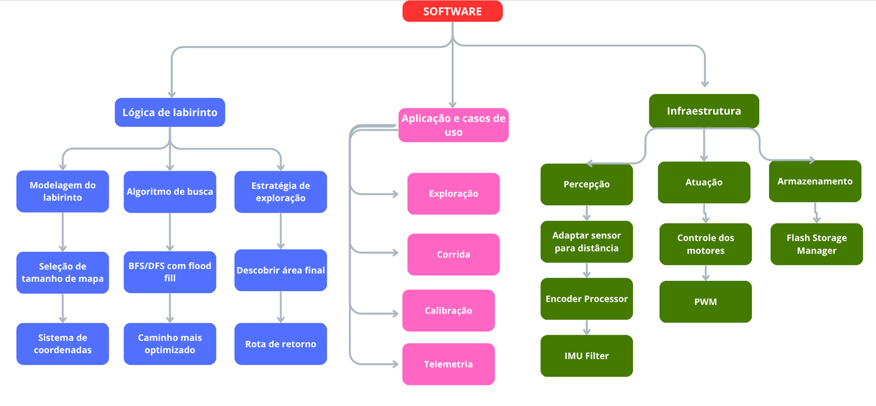
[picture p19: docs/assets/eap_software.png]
  
</p>

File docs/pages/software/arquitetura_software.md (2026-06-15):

# Arquitetura de Software

## 1. Introdução

### 1.1 Visão Geral

Este documento descreve a arquitetura de software do sistema **MicroMouse RataTuring**, apresentando as principais decisões arquiteturais por meio das visões lógica, de processos, de implantação e de dados. Destina-se a desenvolvedores e demais partes interessadas no projeto.

### 1.2 Propósito

O propósito do software do RataTuring é prover a lógica computacional necessária para o veículo navegar de forma autônoma por um labirinto desconhecido, processando variáveis do ambiente e controlando sua locomoção. Integrado a isso, o sistema gerencia o envio contínuo de telemetria para um servidor web, permitindo o monitoramento da operação. Estão fora de escopo deste documento o projeto mecânico e o roteamento de hardware.

---

## 2. Representação Arquitetural

### 2.1 Papel do Software no Sistema

Osoftware atua como o núcleo de controle do Micromouse. No ambiente físico, ele opera de forma isolada, sendo responsável pela percepção e tomada de decisão autônoma. Externamente, interage com os operadores da equipe, fornecendo dados estruturados no painel de monitoramento para análise de desempenho.

### 2.2 Padrão Adotado

**Padrão:** Arquitetura em Camadas e MVT.

**Justificativa:**
A divisão em camadas no microcontrolador permite separar os algoritmos de navegação das rotinas de controle físico, facilitando a manutenção e os testes. No painel web, o padrão MVT agiliza o desenvolvimento ao unificar de forma estruturada a interface de visualização, a recepção de dados e a persistência no banco de dados.

## 3. Metas e Restrições da Arquitetura

### 3.1 Objetivos Arquiteturais

A arquitetura deve garantir estabilidade em tempo real (para a precisão do controle de movimento) e modularidade.

### 3.2 Restrições

As principais restrições englobam a limitação de capacidade de processamento do microcontrolador e a necessidade de garantir que o envio de dados via rede sem fio não interrompa as rotinas críticas de leitura de sensores e atuação nos motores.

---

## 4. Visão Lógica
### 4.1 Diagrama de Alto Nível
O software do sistema RataTuring adota um banco de dados relacional SQLite para a primeira versão. A escolha relacional se justifica pela necessidade de referenciar corridas, labirintos, células e registros do estado atual entre si, facilitando consultas analíticas e comparando resultados de corridas.

### 4.2 Divisão em Camadas

**- Camada de Abstração de Hardware (HAL):** Interface direta com os componentes eletrônicos, responsável pela leitura bruta dos sensores e acionamento dos motores. 

**- Camada de Filtros:** Processamento dos sinais físicos para mitigar ruídos e converter leituras em distâncias métricas confiáveis.   

**- Camada de Navegação e Controle:** Núcleo de inteligência que abriga a matriz do labirinto e a malha de controle PID.    

**- Camada de Comunicação:** Responsável por formatar os dados de estado do robô e gerenciar a transmissão via rede sem fio.
### 4.3 Tecnologias

#### Linguagens de Programação

| Módulo | Tecnologia | Justificativa |
|---|---|---|
|Embarcado | C/C++ | Alto desempenho computacional e eficiência no gerenciamento de memória. |
|Back-end | Python (Django) | Escalabilidade, produtividade e suporte nativo ao gerenciamento de dados relacionais. |
|Front-end | HTML, CSS, JS | Construção de interfaces dinâmicas para renderização do labirinto no navegador. |
|Banco de Dados | SQLite | Banco de dados relacional leve, sem necessidade de servidor dedicado, adequado para armazenamento local da telemetria. |

#### Frameworks Utilizados

| Módulo / Categoria | Tecnologia | Finalidade |
|---|---|---|
| Front-end (Visual) | CSS / Tailwind | Renderização rápida e estruturação visual do mapa e painéis no navegador. |
| Front-end (Rede) | WebSocket API | Conexão contínua com o servidor para atualizações em tempo real. |
| Back-end (Web) | Django 5.x | Servidor principal, gerenciamento de fluxo de dados e integração com banco. |
| Back-end (Rede assíncrona) | Django Channels | Suporte a conexões simultâneas para processar a telemetria contínua. |

## 5. Visão de Processos
O fluxo de controle do robô opera de forma cíclica e concorrente:

**1. Aquisição:** O sistema realiza a varredura contínua dos sensores de distância e codificadores (encoders).

**2. Processamento Lógico:** Os dados são filtrados e repassados ao algoritmo de inteligência, que mapeia as paredes e determina a direção da próxima célula.

**3. Atuação:** A diferença entre a posição real e a desejada alimenta o controlador PID, que ajusta a potência enviada aos motores.

**4. Comunicação Assíncrona:** A diferença entre a posição real e a desejada alimenta o controlador PID, que ajusta a potência enviada aos motores.

## 6. Visão de Implantação

A infraestrutura do sistema é distribuída em três frentes principais:

### 6.1 Nós de Implantação

| Nó / Ambiente | Componentes hospedados | Comunicação / Rede |
|---|---|---|
| Microcontrolador | Firmware do Veículo Autônomo | Comunicação / Rede |
| Servidor Web | Back-end Django e Banco de Dados | TCP/IP e WebSockets |
| Máquina do Operador| Interface Gráfica (Navegador)| HTTP/HTTPS |

## 7. Visão de Dados
### 7.1 Modelo de Dados

#### Diagrama Entidade-Relacionamento (DER)

<figure style="text-align: center; margin: 20px 0;">
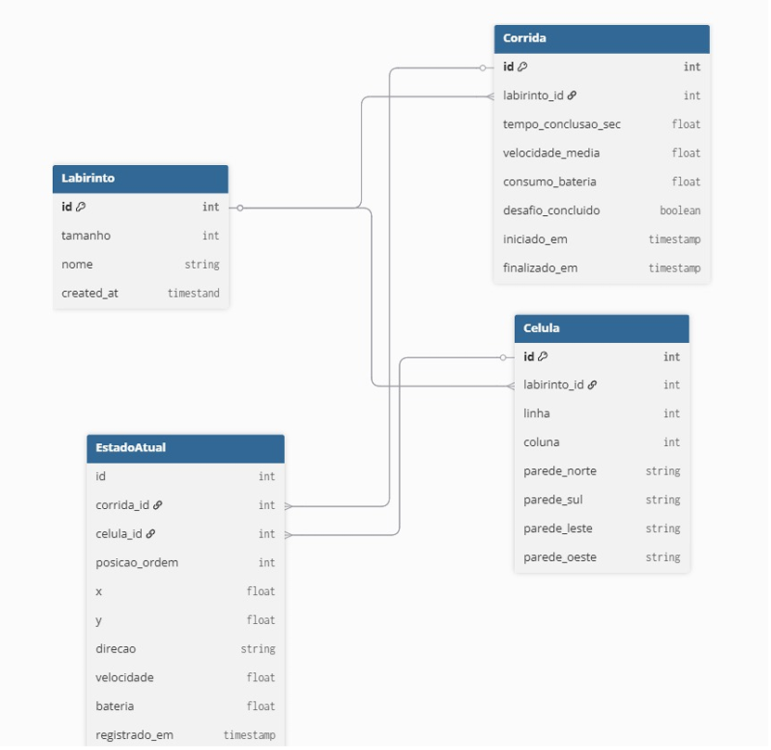
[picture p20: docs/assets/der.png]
Diagrama Entidade-Relacionamento (DER)
    
</figure>

### 7.2 Entidades Principais

| Entidade | Descrição | Relacionamentos |
|---|---|---|
| Labirinto | Representa um labirinto com tamanho padrão (4, 8 ou 16), sem alteração de schema. | Um Labirinto agrupa múltiplas Corridas e Células (1:N). |
| Célula | Cada célula armazena o estado de suas 4 paredes( livre, parede ou desconhecido), permitindo mapeamento incremental. Existe independentemente da corrida. | Cada Célula pertence a um Labirinto (N:1) e pode ser referenciada por múltiplos registros de EstadoAtual. |
| Corrida | Registra dados agregados e finais: tempo total, velocidade média e bateria, calculados ao final da partida. | Uma Corrida pertence a um Labirinto (N:1) e agrupa múltiplos registros de EstadoAtual (1:N) |
| EstadoAtual | Registra cada ponto instantâneo de posição do robô ao longo da corrida, capturado a cada célula visitada. Os campos **velocidade_cms** e **bateria_v** representam valores no momento exato da visita. O campo **posicao_ordem** garante a reconstituição do trajeto a reconstituição do trajeto na ordem correta. | Cada registro pertence a uma Corrida (N:1) e referencia uma Célula (N:1). |

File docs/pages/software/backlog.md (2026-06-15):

# Backlog do Produto de Software

O **Backlog do Produto** foi elaborado com o objetivo de organizar e priorizar os requisitos necessários para o desenvolvimento do sistema de monitoramento e navegação autônoma do Micromouse. Sua estrutura é baseada em **histórias de usuário**, **requisitos não funcionais** e **critérios de aceitação**, permitindo a rastreabilidade das funcionalidades ao longo do ciclo de desenvolvimento.

As funcionalidades foram agrupadas em **épicos** que representam os principais domínios do sistema, abrangendo desde a navegação autônoma do robô e a comunicação de telemetria até a interface web e o histórico de corridas.

Cada história de usuário foi escrita seguindo o padrão “**Como** *[ator]*, **quero** *[funcionalidade]*, **para** *[benefício]*” e classificada conforme a técnica de priorização **MoSCoW** (Must Have, Should Have, Could Have e Won't Have), auxiliando na definição do escopo de cada entrega.

Além dos requisitos funcionais, o backlog contempla requisitos não funcionais relacionados à autonomia do robô, desempenho da telemetria, persistência dos dados e escalabilidade da solução. Os critérios de aceitação e as tarefas associadas a cada item servem como referência para implementação, validação e acompanhamento das atividades do projeto.

## Product Backlog

### Épico B: Navegação Autônoma

| ID | Título da História | MoSCoW | História de Usuário | Critérios de Aceite |
| --- | --- | --- | --- | --- |
| **US-05** | Explorar o Labirinto | Must Have | Como avaliador, quero que o robô explore células desconhecidas para construir um mapa do ambiente. | **CA-05-01:** Dado que existam células desconhecidas, quando o robô explorar o ambiente, então deverá priorizar sua visita.<br><br>**CA-05-02:** Dado que uma nova célula seja visitada, quando a exploração ocorrer, então o mapa deverá ser atualizado.<br><br>**CA-05-03:** Dado que a exploração esteja em andamento, quando uma célula já conhecida for encontrada, então o sistema deverá manter a consistência do mapa. |
| **US-06** | Detectar Obstáculos  | Must Have | Como avaliador, quero que o robô identifique obstáculos para evitar colisões. | **CA-06-01:** Dado que exista um obstáculo à frente, quando os sensores realizarem a leitura, então o avanço deverá ser bloqueado.<br><br>**CA-06-02:** Dado que exista uma parede lateral, quando ela for detectada, então deverá ser registrada no mapa.<br><br>**CA-06-03:** Dado que o sistema calcule possíveis movimentos, quando houver uma célula bloqueada, então ela não deverá ser considerada navegável. |
| **US-07** | Atualizar Mapa | Must Have | Como avaliador, quero que o mapa seja atualizado conforme novas informações são descobertas. | **CA-07-01:** Dado que novas informações sejam descobertas, quando forem processadas, então o mapa deverá ser atualizado.<br><br>**CA-07-02:** Dado que uma parede seja identificada, quando a célula for atualizada, então a informação deverá ser persistida.<br><br>**CA-07-03:** Dado que o mapa seja transmitido ao sistema web, quando solicitado, então deverá refletir o estado atual conhecido. |
| **US-08** | Encontrar Objetivo | Must Have | Como avaliador, quero que o robô encontre a região objetivo do labirinto. | **CA-08-01:** Dado que o robô alcance a região objetivo, quando sua posição for analisada, então o objetivo deverá ser considerado encontrado.<br><br>**CA-08-02:** Dado que o objetivo seja encontrado, quando a exploração estiver ativa, então a corrida deverá ser marcada como concluída.<br><br>**CA-08-03:** Dado que a conclusão seja detectada, quando a telemetria for enviada, então o status deverá ser atualizado. |
| **US-09** | Planejar Rota | Must Have | Como avaliador, quero que o robô calcule rotas eficientes para alcançar o objetivo. | **CA-09-01:** Dado que exista um mapa conhecido, quando o algoritmo calcular uma rota, então deverá retornar um caminho válido.<br><br>**CA-09-02:** Dado que existam múltiplas rotas possíveis, quando forem comparadas, então deverá ser escolhida a mais eficiente.<br><br>**CA-09-03:** Dado que uma rota seja gerada, quando o robô iniciar o deslocamento, então deverá conseguir percorrê-la.<br><br>**CA-09-04:** Dado que haja um obstáculo, quando os sensores o detectarem, então deverá replanejar a rota. |

---

### Épico C: Telemetria

| ID | Título da História | MoSCoW | História de Usuário | Critérios de Aceite |
| --- | --- | --- | --- | --- |
| **US-10** | Comunicação em Tempo Real | Must Have  | Como avaliador, quero receber dados do robô em tempo real para acompanhar a corrida. | **CA-10-01:** Dado que o robô altere sua posição, quando novos dados forem enviados, então a interface deverá atualizar automaticamente.<br><br>**CA-10-02:** Dado que o mapa seja modificado, quando novas informações forem recebidas, então as alterações deverão aparecer em tempo real.<br><br>**CA-10-03:** Dado que exista comunicação ativa, quando ocorrer transmissão de dados, então as informações deverão permanecer sincronizadas. |
| **US-11** | Reconexão Automática | Could Have | Como avaliador, quero que a conexão seja restabelecida automaticamente para continuar acompanhando a corrida. | **CA-11-01:** Dado que exista perda de conexão, quando o sistema detectar a falha, então deverá iniciar tentativas automáticas de reconexão.<br><br>**CA-11-02:** Dado que a conexão seja restabelecida, quando a comunicação retornar, então o status deverá ser atualizado.<br><br>**CA-11-03:** Dado que o operador esteja monitorando o sistema, quando ocorrer uma desconexão, então deverá receber indicação visual. |

---

### Épico D: Interface Web

| ID | Título da História | MoSCoW | História de Usuário | Critérios de Aceite |
| --- | --- | --- | --- | --- |
| **US-12** | Iniciar Sessão de Monitoramento | Must Have | Como avaliador, quero iniciar uma sessão de monitoramento para acompanhar uma nova corrida. | **CA-12-01:** Dado que o operador deseje iniciar uma corrida, quando criar uma sessão, então deverá ser gerado um identificador único.<br><br>**CA-12-02:** Dado que a sessão seja iniciada, quando a telemetria começar a ser recebida, então os dados deverão ser associados à sessão correta. |
| **US-13** | Exibir Posição em Tempo Real | Must Have | Como avaliador, quero visualizar a posição atual do robô durante a corrida. | **CA-13-01:** Dado que o robô se mova, quando a posição for atualizada, então sua representação gráfica deverá acompanhar o movimento.<br><br>**CA-13-02:** Dado que a interface esteja aberta, quando novos dados forem recebidos, então a atualização deverá ocorrer sem recarregar a página. |
| **US-14** | Exibir Caminho Percorrido | Must Have | Como avaliador, quero visualizar o trajeto percorrido pelo robô. | **CA-14-01:** Dado que o robô percorra o labirinto, quando visitar novas células, então o trajeto deverá ser registrado.<br><br>**CA-14-02:** Dado que a corrida seja concluída, quando o mapa for exibido, então o caminho percorrido deverá permanecer visível. |
| **US-15** | Exibir Status do Robô | Should Have | Como avaliador, quero acompanhar o estado operacional do robô. | **CA-15-01:** Dado que o robô esteja ativo, quando a interface for atualizada, então o status deverá indicar as condições do hardware.<br><br>**CA-15-02:** Dado que exista comunicação em tempo real, quando ocorrer uma desconexão, então a interface deverá informar a perda de conexão.<br><br>**CA-15-03:** Dado que ocorra uma falha, quando o sistema identificá-la, então o status deverá informar o problema. |
| **US-16** | Exibir Status do Desafio | Should Have | Como avaliador, quero acompanhar o progresso da corrida. | **CA-16-01:** Dado que a corrida seja iniciada, quando a execução começar, então o status deverá indicar "Em andamento".<br><br>**CA-16-02:** Dado que o objetivo seja encontrado, quando a corrida terminar, então o status deverá indicar "Sucesso". |

---

### Épico E: Histórico de Corridas

| ID | Título da História | MoSCoW | História de Usuário | Critérios de Aceite |
| --- | --- | --- | --- | --- |
| **US-17** | Registrar Dados Finais | Must Have | Como avaliador, quero que os resultados da corrida sejam armazenados para consultas futuras. | **CA-17-01:** Dado que uma corrida seja finalizada, quando os dados forem persistidos, então tempo, bateria, trajeto e resultado deverão ser armazenados.<br><br>**CA-17-02:** Dado que o sistema seja reiniciado, quando os dados forem consultados, então deverão permanecer disponíveis.<br><br>**CA-17-03:** Dado que ocorra uma desconexão do sistema, quando os dados forem solicitados, então o sistema web deverá ser capaz de coletá-los e exibi-los. |
| **US-18** | Consultar Histórico | Must Have | Como avaliador, quero visualizar todas as corridas registradas. | **CA-18-01:** Dado que existam corridas registradas, quando o histórico for acessado, então todas deverão ser listadas.<br><br>**CA-18-02:** Dado que uma corrida esteja listada, quando for exibida, então deverá apresentar suas informações resumidas. |
| **US-19** | Consultar Corrida Individual | Must Have | Como avaliador, quero analisar detalhadamente uma corrida específica. | **CA-19-01:** Dado que uma corrida seja selecionada, quando sua página for aberta, então todos os dados registrados deverão ser exibidos.<br><br>**CA-19-02:** Dado que exista um trajeto armazenado, quando a corrida for consultada, então ele deverá ser visualizado. |

---

## Tabela de Requisitos Não Funcionais (RNF)

| ID HU | REQ | Pertence ao USM | Descrição | Critérios de Aceitação | Tarefas |
| --- | --- | --- | --- | --- | --- |
| RNF-SW-001 | O painel web não deve enviar comandos ao Micromouse durante a corrida. | Todas as releases > Autonomia | Garante que a decisão do robô permanece embarcada e independente. | Revisão da interface não encontra botões/endpoints de comando; testes confirmam que mensagens do frontend não alteram rota, velocidade ou estado de decisão. | Revisar rotas; revisar WebSocket; criar teste negativo; documentar restrição. |
| RNF-SW-002 | A telemetria não deve bloquear a rotina de navegação do Micromouse. | Release 2 > EP-SW-05 | O envio de dados deve ocorrer em paralelo ou com tolerância a falha de rede. | Em simulação, se o servidor estiver indisponível, o algoritmo continua decidindo rotas; falha de envio gera registro de erro sem parar navegação. | Definir fila/buffer; tratar falha de rede; criar teste de servidor indisponível. |
| RNF-SW-003 | O software deve aceitar labirinto 4x4 e ter modelagem preparada para 8x8 e 16x16. | Release 1 > EP-SW-02 | O tema oficial cita três tamanhos. | Criar labirintos 4x4, 8x8 e 16x16 no modelo sem alterar o schema. | Validar tamanho; testar criação; alinhar escopo visual com a equipe. |
| RNF-SW-004 | Os dados armazenados devem ser consultáveis após encerramento da aplicação. | Release 1 > EP-SW-02 | O SQLite deve manter resultados entre execuções. | Após reiniciar o backend, corridas previamente salvas continuam sendo retornadas pela API. | Testar persistência; configurar arquivo SQLite; documentar local do banco. |

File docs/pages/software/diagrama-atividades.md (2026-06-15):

# Diagrama de atividades UML
## 1. Contexto
O **Diagrama de atividades** é um diagrama comportamental da UML utilizado para **modelar o fluxo de um sistema**, descrevendo a sequência de atividades executadas, os pontos de decisão, os fluxos paralelos e a troca de dados entre os participantes. No contexto do projeto, o diagrama permite visualizar como o Micromouse opera desde sua inicialização até a publicação dos resultados. As swimlanes (Usuário, Sistema Embarcado, Hardware e Sistema Web) identificam claramente em quais domínios cada atividade é executada.
### 1. Diagrama
<figure style="text-align: center; margin: 20px 0;">
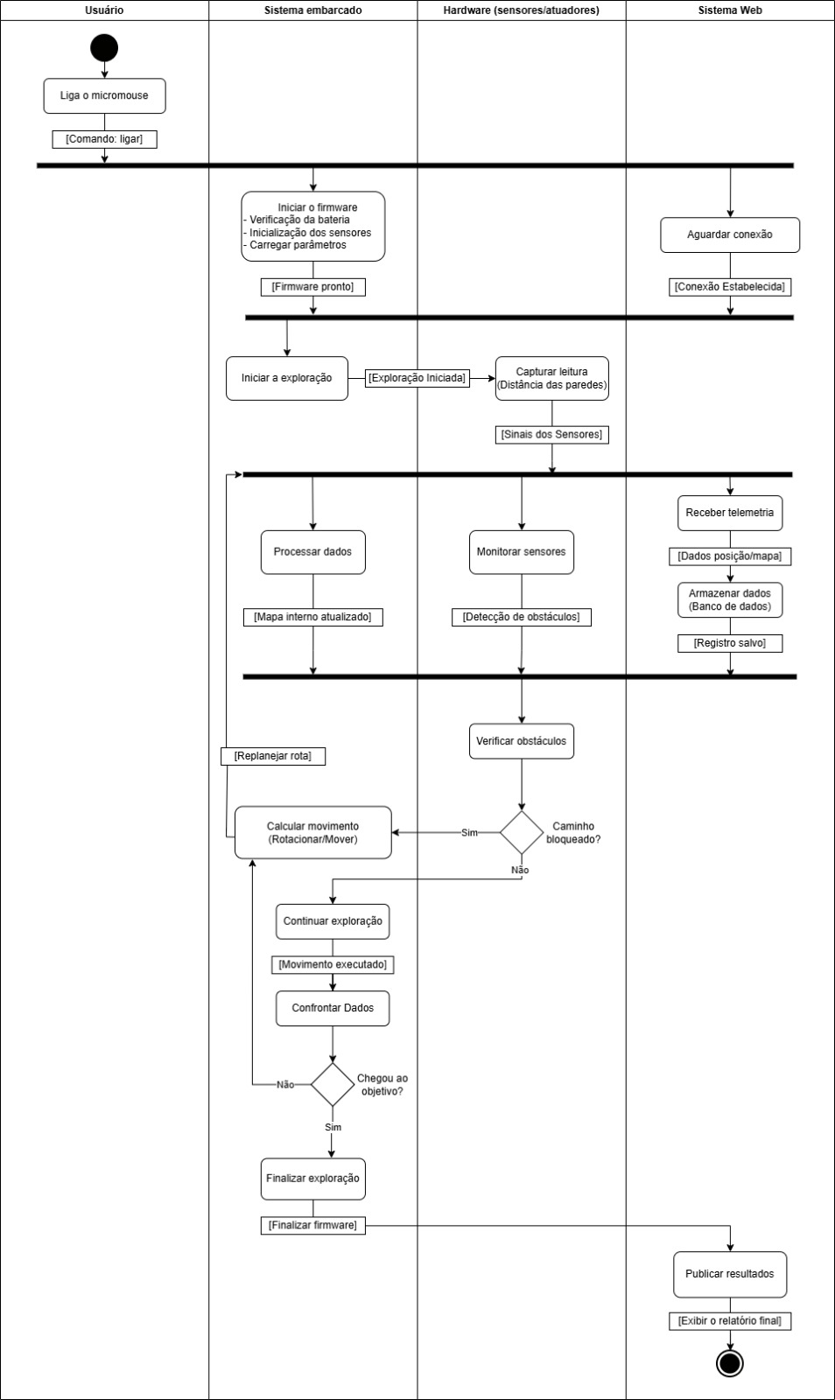
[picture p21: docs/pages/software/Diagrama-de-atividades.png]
Diagrama Entidade-Relacionamento (DER)
    
</figure>

## 2. Detalhamento
**1. Usuário:** ator humano responsável pelo gatilho inicial.

**2. Sistema Embarcado:** núcleo lógico de controle e processamento.

**3. Hardware (Sensores/Atuadores):** interface física com o labirinto.

**4. Sistema Web:** interface externa de monitoramento e armazenamento.

### 2.1 Fluxo de Comportamento
**A. Inicialização e paralelismo (bifurcação):** O usuário liga o Micromouse; o sinal [Comando:
ligar] dispara duas frentes paralelas — inicialização do firmware no sistema embarcado e
aguardo de conexão no sistema web. Uma barra de sincronização garante que a exploração
só inicie após ambos estarem prontos.

**B. Exploração e monitoramento:** O hardware captura leituras dos sensores, que alimentam
três processos simultâneos: atualização do mapa interno (embarcado), monitoramento de
obstáculos (hardware) e recepção e armazenamento de telemetria (sistema web).

**C. Tomada de decisão e controle (Nós de Decisão):** o dinamismo do sistema é definido por
dois pontos críticos de decisão:

**Verificação de obstáculos:** o sistema questiona "Caminho bloqueado?".

**Sim:** aciona o cálculo de movimento (rotação/desvio) e retorna ao replanejamento de rota.

**Não:** segue para a atividade de "Continuar exploração".

**Verificação de objetivo:** após o movimento e o confronto de dados, o sistema questiona:
"Chegou ao objetivo?".

**Sim:** direciona para o encerramento.

**Não:** o fluxo retorna ao ponto de processamento de dados para continuar a busca.

**D. Finalização e saída ao atingir o objetivo:**

1. O sistema embarcado executa a atividade "Finalizar exploração".

2. O sinal [Finalizar firmware] é enviado ao sistema web.

**Resultado final:** o sistema web executa a atividade "Publicar resultados", gerando o [Relatório
final]. O fluxo encerra no estado final (círculo com borda).

## 3. Tabela de Insumos
| Atividade | Insumos (Entradas) | Saídas |
| :--- | :--- | :--- |
| Ligar o micromouse | Ação do usuário | [Comando: ligar] |
| Iniciar o firmware | [Comando: ligar], bateria, sensores, parâmetros do sistema | [Firmware pronto] |
| Aguardar conexão | [Comando: ligar], Inicialização do sistema web | [Conexão Estabelecida] |
| Iniciar a exploração | [Firmware pronto] e [Conexão Estabelecida] | [Exploração iniciada] |
| Capturar leitura | [Exploração iniciada], leituras dos sensores, distância das paredes | [Sinais dos Sensores] |
| Processar dados | [Sinais dos Sensores], mapa interno anterior | [Mapa interno atualizado] |
| Monitorar sensores | [Sinais dos Sensores] | [Detecção de obstáculos] |
| Receber telemetria | [Sinais dos Sensores], dados enviados pelo sistema embarcado | [Dados posição/mapa] |
| Armazenar dados | [Dados posição/mapa] | [Registro salvo] |
| Verificar obstáculos | [Mapa interno atualizado]; [Detecção de obstáculos] e [Registro salvo] | Decisão: caminho bloqueado ou livre |
| Calcular movimento (Rotacionar/Mover) | Decisão: caminho bloqueado ou objetivo não alcançado | [Replanejar rota] |
| Continuar exploração | Decisão: caminho livre | [Movimento executado] |
| Confrontar dados | [Movimento executado], mapa interno atualizado | Decisão: verificação do objetivo |
| Finalizar exploração | Decisão: objetivo alcançado | [Finalizar firmware] |
| Publicar resultados | [Finalizar firmware] | [Exibir o relatório final] |

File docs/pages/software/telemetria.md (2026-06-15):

# Sistema de Telemetria

## 1. Objetivo

O sistema de telemetria é responsável por **coletar**, **transmitir**, **armazenar** e **disponibilizar** informações geradas pelo Micromouse durante sua execução.

A telemetria possui quatro objetivos principais:

* Permitir a visualização da corrida em tempo real;
* Armazenar informações para análises posteriores;
* Possibilitar a reprodução completa de execuções;
* Fornecer métricas para avaliação do desempenho do robô.

---

## 2. Arquitetura Geral

```text
ESP32
 ├── Sensores
 ├── Controle de Movimento
 ├── Algoritmo de Navegação
 ├── Gerenciador de Eventos
 ├── Buffer de Telemetria
 └── Cliente WebSocket
          │
          ▼
Backend
 ├── WebSocket Server
 ├── Persistência
 ├── API
 └── Processamento
          │
          ▼
Banco de Dados
          │
          ▼
Frontend
```

---

## 3. Princípios da Solução

### 3.1 Arquitetura Orientada a Eventos

A telemetria será baseada em eventos.

O firmware não realizará streaming contínuo de sensores ou estados internos.

Apenas acontecimentos relevantes serão transmitidos.

**Exemplos:**

* início de corrida;
* descoberta de nova célula;
* descoberta de paredes;
* cálculo da rota ótima;
* finalização da corrida.

**Essa abordagem reduz:**

* consumo de banda;
* uso de memória;
* volume de armazenamento.

---

### 3.2 Fonte Primária dos Dados

A ESP32 é considerada a fonte primária dos dados.

O backend atua como camada de persistência.

Caso a conexão seja perdida:

* os eventos continuam sendo gerados;
* os eventos permanecem armazenados localmente;
* a transmissão é retomada após reconexão.

---

## 4. Convenção Espacial

### 4.1 Sistema Cartesiano

#### Origem:

```text
(0,0)
```

Localizada no canto inferior esquerdo do labirinto.

#### Eixo X

Cresce para a direita (Leste).

```text
x++
```

#### Eixo Y

Cresce para cima (Norte).

```text
y++
```

---

### 4.2 Movimentação

| Direção | Operação |
| --- | --- |
| Norte | y++ |
| Sul | y-- |
| Leste | x++ |
| Oeste | x-- |

---

## 5. Estrutura Base dos Eventos

Todos os eventos devem possuir a seguinte estrutura:

```json
{
  "event_id": 1,
  "id_corrida": 1,
  "timestamp_ms": 1234,
  "tipo": "event_name",
  "payload": {}
}
```

#### Campos

| Campo | Descrição |
| --- | --- |
| event_id | Identificador incremental do evento |
| id_corrida | Identificador da execução |
| timestamp_ms | Tempo desde o início da corrida |
| tipo | Tipo do evento |
| payload | Dados específicos do evento |

---

## 6. Eventos

### 6.1 run_started

Disparado uma única vez ao iniciar uma corrida.

```json
{
  "event_id": 1,
  "id_corrida": 1,
  "timestamp_ms": 0,
  "tipo": "run_started",
  "payload": {
    "dimensao": 16,
    "tentativa": 1,
    "bateria": 100
  }
}
```

#### Campos

| Campo | Descrição |
| --- | --- |
| dimensao  | 4, 8 ou 16 |
| tentativa | Número da tentativa |
| bateria | Percentual inicial da bateria |

---

### 6.2 cell_discovered

Disparado sempre que o robô entra em uma nova célula.

```json
{
  "event_id": 2,
  "id_corrida": 1,
  "timestamp_ms": 1234,
  "tipo": "cell_discovered",
  "payload": {
    "x": 2,
    "y": 1,
    "linha": 1,
    "coluna": 2,
    "parede_norte": false,
    "parede_sul": false,
    "parede_leste": true,
    "parede_oeste": false,
    "direcao": "N",
    "velocidade": 0.3,
    "bateria": 97.3
  }
}
```

#### Campos

| Campo | Descrição |
| --- | --- |
| x | Coordenada X (coluna, cresce para Leste) |
| y | Coordenada Y (linha, cresce para Norte) |
| linha | Alias de y — usado pelo backend para indexar célula |
| coluna | Alias de x — usado pelo backend para indexar célula |
| parede_norte | `true` se há parede ao Norte |
| parede_sul | `true` se há parede ao Sul |
| parede_leste | `true` se há parede ao Leste |
| parede_oeste | `true` se há parede ao Oeste |
| direcao | Direção atual do robô: `"N"`, `"S"`, `"L"`, `"O"` |
| velocidade | Velocidade instantânea em m/s |
| bateria | Percentual atual da bateria neste evento (%) |

---

### 6.3 optimal_path_calculated

Disparado quando o algoritmo encontrar a rota ótima.

```json
{
  "event_id": 50,
  "id_corrida": 1,
  "timestamp_ms": 9000,
  "tipo": "optimal_path_calculated",
  "payload": {
    "rota": [
      [0,0],
      [0,1],
      [0,2],
      [1,2],
      [2,2]
    ]
  }
}
```

#### Objetivo

Permitir que a interface web desenhe a rota calculada pelo FloodFill.

---

### 6.4 fast_run_started

Disparado imediatamente antes da corrida rápida.

```json
{
  "event_id": 51,
  "id_corrida": 1,
  "timestamp_ms": 9010,
  "tipo": "fast_run_started"
}
```

---

### 6.5 run_finished

Disparado uma única vez ao finalizar a corrida.

```json
{
  "event_id": 100,
  "id_corrida": 1,
  "timestamp_ms": 14250,
  "tipo": "run_finished",
  "payload": {
    "sucesso": true,
    "v_med": 0.22,
    "bateria": 88
  }
}
```

#### Campos

| Campo | Descrição |
| --- | --- |
| sucesso | Conclusão da missão |
| v_med | Velocidade média |
| bateria | Bateria restante |

---

## 7. Comunicação

### 7.1 Protocolo

A comunicação ocorrerá utilizando WebSocket.

#### Objetivo

* Baixa latência;
* Comunicação bidirecional;
* Atualizações em tempo real.

---

## 8. Persistência Local

A ESP32 deverá manter um buffer local contendo eventos ainda não confirmados.

**Estrutura conceitual:**

```cpp
struct TelemetryEvent {
    uint32_t event_id;
    uint32_t timestamp_ms;
};
```

**Os eventos podem permanecer:**

* em RAM durante a execução;
* em LittleFS para persistência prolongada.

---

## 9. Reconexão

### 9.1 Perda de Conexão

Ao detectar desconexão:

1. Continuar gerando eventos;
2. Continuar armazenando eventos localmente;
3. Tentar reconectar automaticamente;
4. Reenviar eventos pendentes.

---

### 9.2 ACK

O backend poderá confirmar o recebimento:

```json
{
  "ack": 100
}
```

Significando que todos os eventos até o ID 100 foram persistidos.

Após confirmação, os eventos podem ser removidos do buffer.

---

## 10. Banco de Dados

O backend deverá armazenar:

### 10.1 Corridas

* id_corrida
* data
* dimensão
* tentativa
* duração
* sucesso

### 10.2 Eventos

* event_id
* id_corrida
* timestamp
* tipo
* payload

---

## 11. Reprodução de Corridas

A reprodução deverá ser possível utilizando apenas os eventos armazenados.

**Fluxo:**

1. Recuperar eventos da corrida;
2. Ordenar por timestamp;
3. Reaplicar os eventos;
4. Reconstruir o estado do labirinto.

---

## 12. Métricas Futuras

A arquitetura deverá permitir expansão para:

* Telemetria de sensores;
* Telemetria de motores;
* Corrente dos motores;
* Temperatura da ESP32;
* Tensão da bateria;
* Consumo energético;
* Estatísticas por algoritmo;
* Comparação entre corridas.

---

## 13. Responsabilidades

### 13.1 Firmware

* Gerar eventos;
* Gerenciar buffer local;
* Transmitir eventos;
* Realizar retransmissão após reconexão.

### 13.2 Backend

* Receber eventos;
* Validar eventos;
* Persistir eventos;
* Disponibilizar APIs.

### 13.3 Frontend

* Visualização em tempo real;
* Replay de corridas;
* Dashboard de métricas.

### 13.4 Equipe de Dados

* Definição de métricas;
* Geração de relatórios;
* Análises estatísticas.

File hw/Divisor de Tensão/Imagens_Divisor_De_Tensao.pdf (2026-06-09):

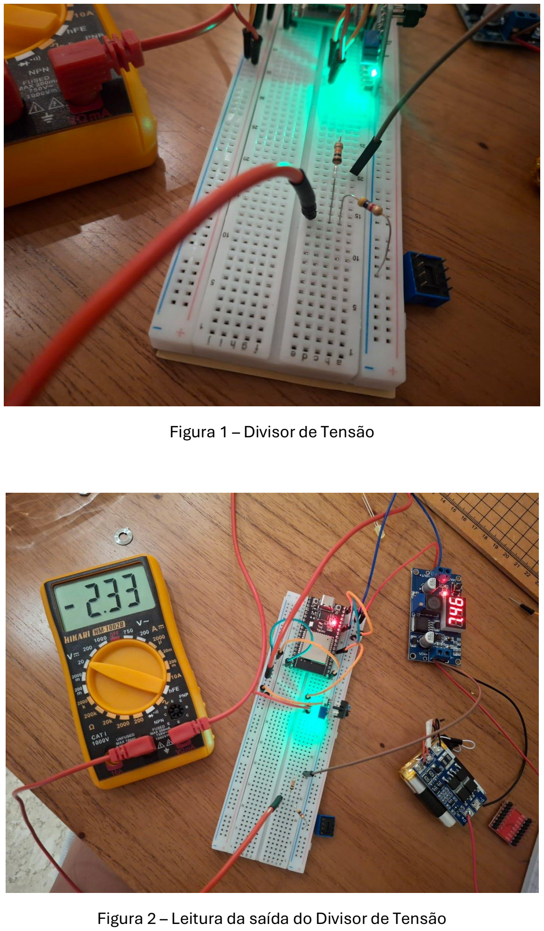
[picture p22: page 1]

Figura 1 – Divisor de Tensão

Figura 2 – Leitura da saída do Divisor de Tensão

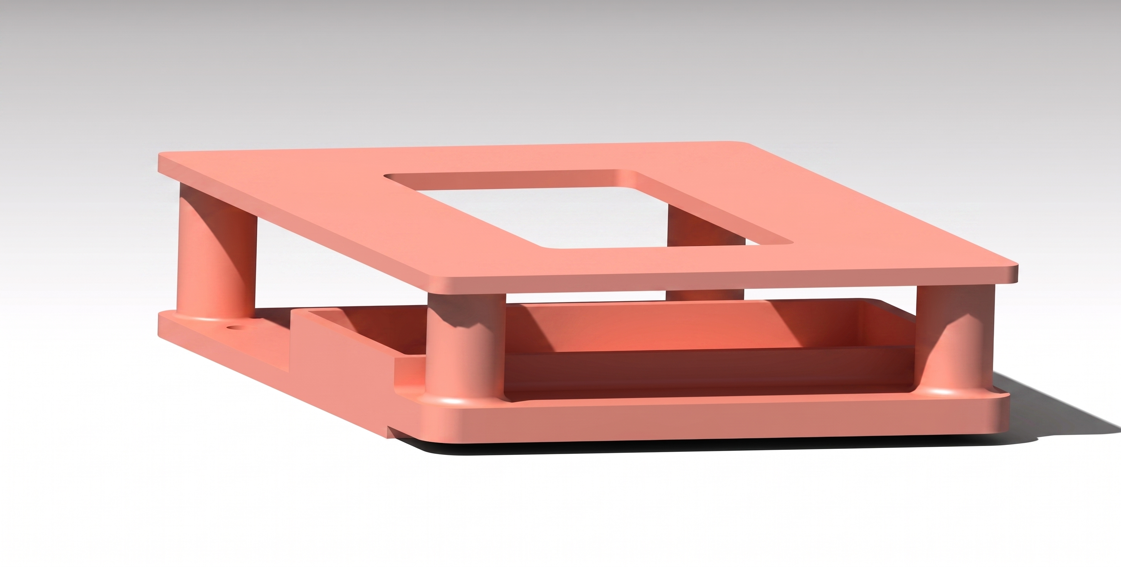
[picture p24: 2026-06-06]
mec/Robô/media/render chassis.png

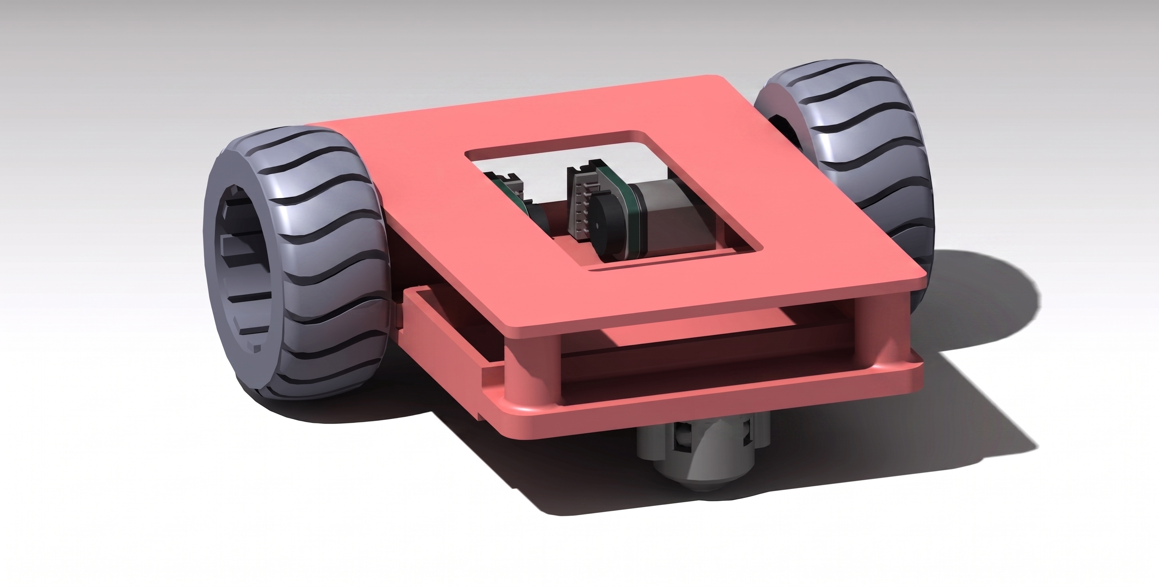
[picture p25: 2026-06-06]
mec/Robô/media/render final chassis.png

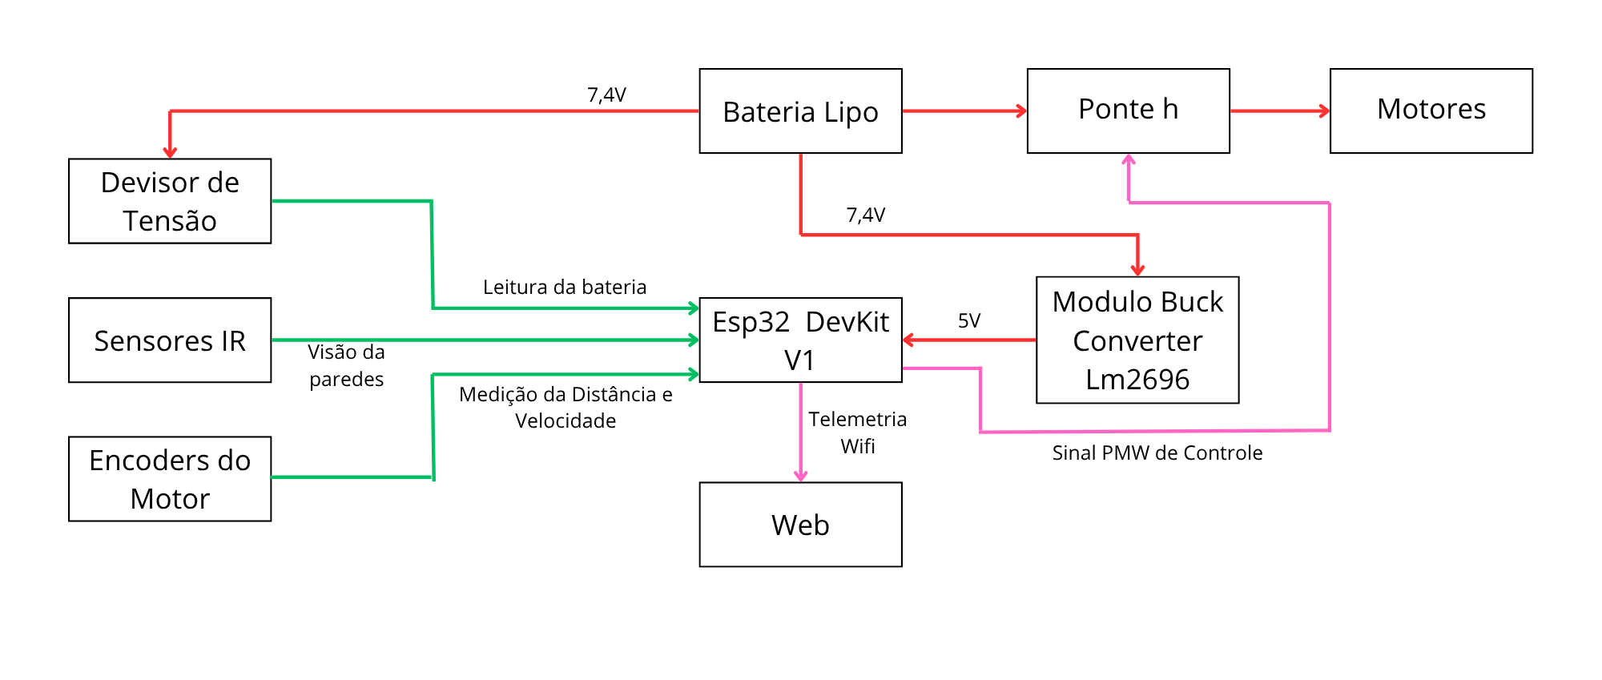
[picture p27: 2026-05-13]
hw/Projeto Conceitual de Eletrônica ED1/Diagrama_De_Blocos_Hardware.png

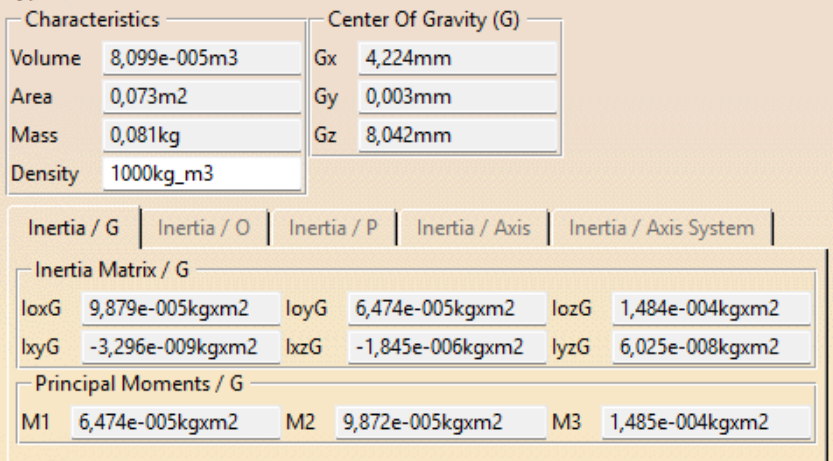
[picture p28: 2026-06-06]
mec/Robô/media/Valores de inercia chassi.png

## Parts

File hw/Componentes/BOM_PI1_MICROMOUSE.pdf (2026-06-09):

ID | COMPONENTE | ESPECIFICAÇÃO | QUANTIDADE | REFERÊNCIA | FORNECEDOR / LINK | CUSTO UNITÁRIO CUSTO TOTAL | | STATUS | DATA PREVISTA | RECEBIDO
1 | Microcontrolador | Módulo WiFi NodeMCU ESP-32S + Bluetooth (38 pinos) | 1 | MOD | HU Infinito (https://www.huinfinito.com.br/) | 73,9 | 73,9 | COMPRADO | 29/05/2026 | SIM
2 | Sensores Infravermelhos | TCRT5000 (Nota: 4 para uso no robô, 2 de reserva). | 6 | MOD2 a MOD5 | https://a.co/d/05HZFIbL | 12,5 | 74,97 | COMPRADO | 11/05/2026 | SIM
3 | Buck Converter | LM2596 | 1 | MOD6 | https://a.co/d/0aN8AAWz | 25,5 | 25,5 | COMPRADO | 11/05/2026 | SIM
4 | Ponte H | TB6612FNG | 1 | MOD7 | Link (https://www.mercadolivre.com.br/driver-tb6612fng-duplo-ponte-h-de-motor-dc-ou-passo/up/MLBU1163035955) | 33,9 | 33,9 | COMPRADO | 16-19/05/2026 | SIM
208,27

B

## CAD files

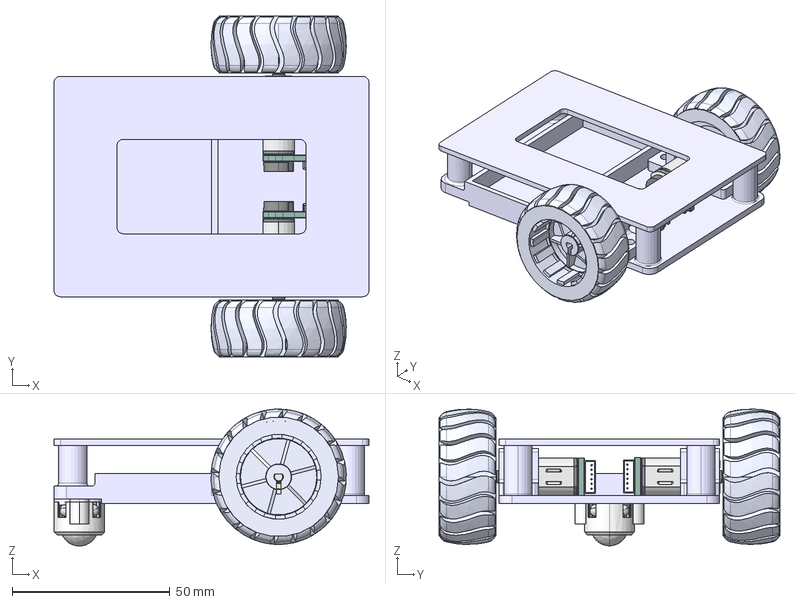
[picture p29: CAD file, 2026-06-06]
mec/Robô/Final chassis/final chassis.stp
100.0 x 108.2 x 43.5 mm
1st level
new clamp x 2
N20 Mini Micro Metall Gear Motor DC 3/6/12V x 2
Housing x 2
Hub x 2
Ш.01.Шарик 12
Ш.03.Створка
Ш.04.Корпус
ISO 7045 - M2 x 6 - 4.8 - H x 2
Ш.02.Шарик 4 x 4

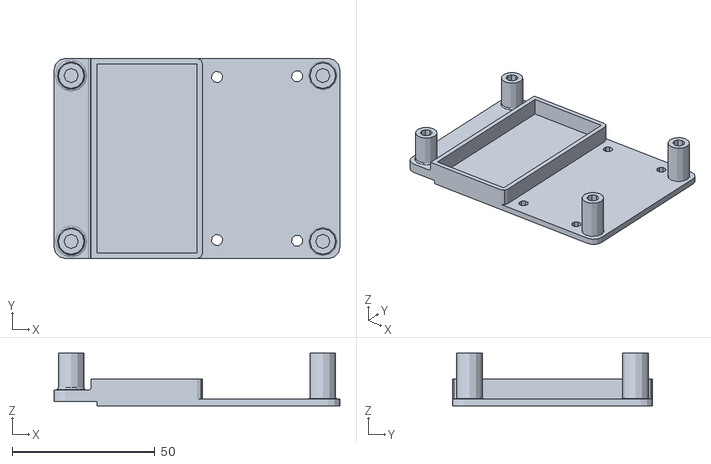
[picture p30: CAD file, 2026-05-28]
mec/STLs para impressão 3D/1st level.stl
100.0 x 70.0 x 18.5

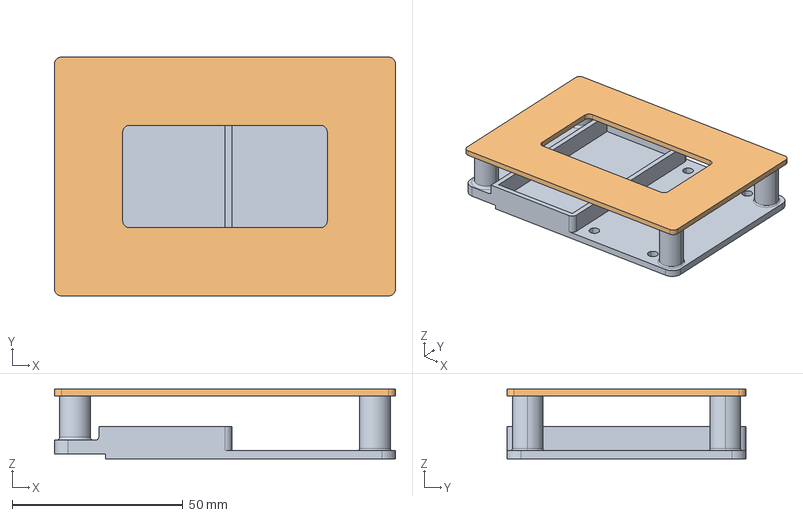
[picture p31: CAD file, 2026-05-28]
mec/Robô/Final chassis/chassis.stp
100.0 x 70.0 x 20.5 mm
1st level

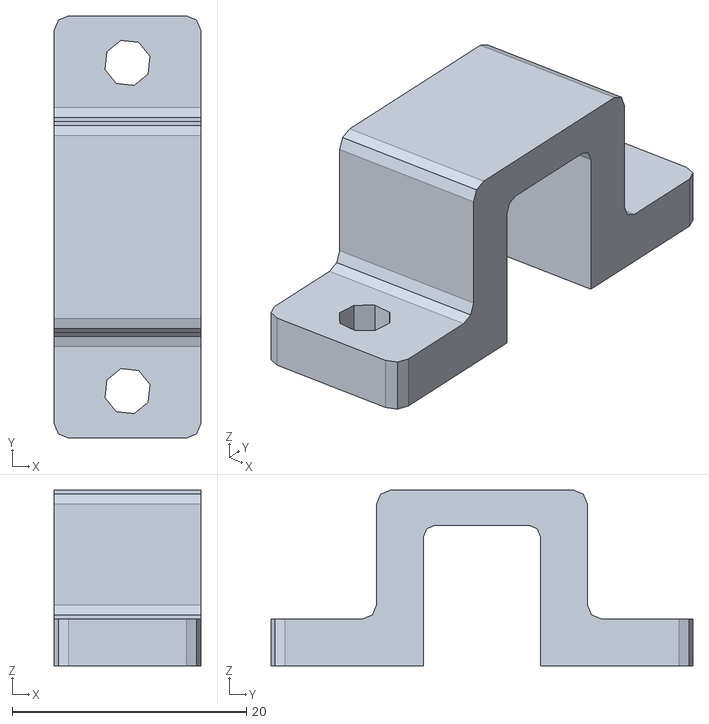
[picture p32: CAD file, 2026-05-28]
mec/STLs para impressão 3D/clamp for motor.stl
12.5 x 36.0 x 15.0

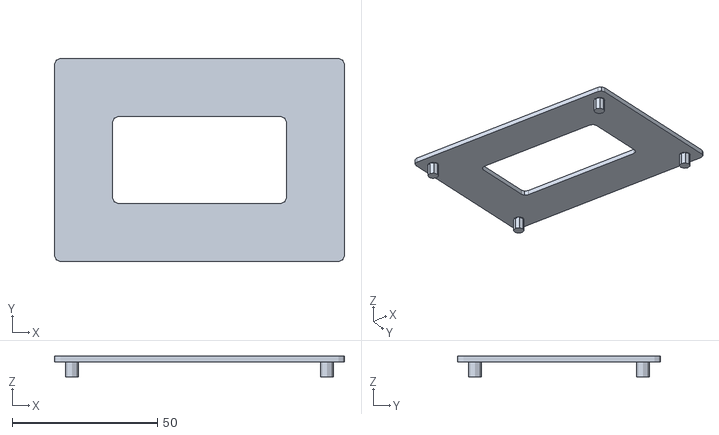
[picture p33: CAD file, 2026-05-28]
mec/STLs para impressão 3D/2nd level.stl
100.0 x 70.0 x 7.20

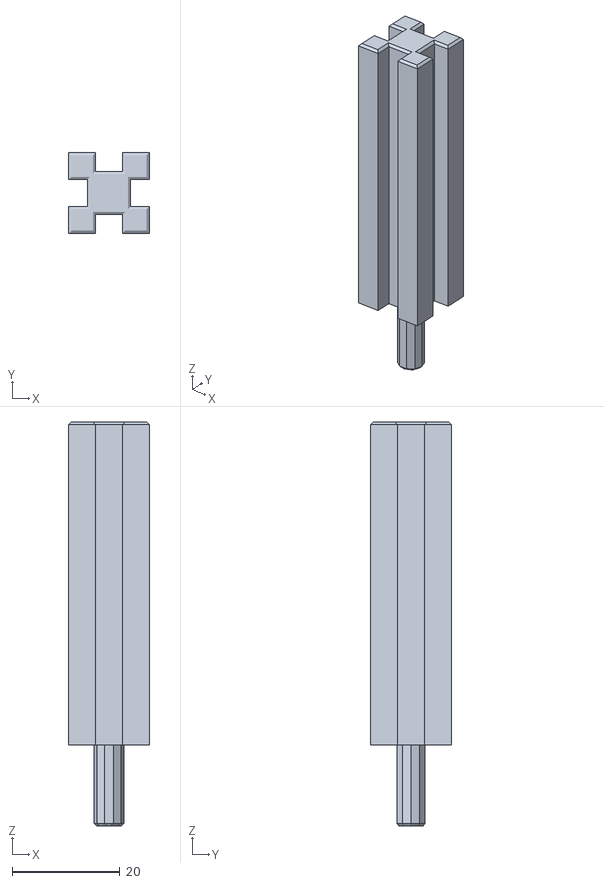
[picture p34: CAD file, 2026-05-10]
mec/STLs para impressão 3D/Pilar de Encaixe.stl
15.0 x 15.0 x 75.0

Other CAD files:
mec/CAD Labirinto/Base (chapa).CATPart
mec/CAD Labirinto/Labirinto Assembly.CATProduct
mec/CAD Labirinto/Pilar de Encaixe.CATPart
mec/Robô/Final chassis/1st level.CATPart
mec/Robô/Final chassis/2nd level.CATPart
mec/Robô/Final chassis/Ball Caster 12mm.CATProduct
mec/Robô/Final chassis/Housing.CATPart
mec/Robô/Final chassis/Hub.CATPart
mec/Robô/Final chassis/ISO 7045 - M2 x 6 - 4.8 - H.CATPart
mec/Robô/Final chassis/N20 Mini Micro Metall Gear Motor DC 3-6-12V v1.CATPart
mec/Robô/Final chassis/Roda.CATProduct
mec/Robô/Final chassis/_NPart#4272.CATPart
mec/Robô/Final chassis/_NPart#4273.CATPart
mec/Robô/Final chassis/_NPart#4274.CATPart
mec/Robô/Final chassis/_NPart#4276.CATPart
mec/Robô/Final chassis/chassis.CATProduct
mec/Robô/Final chassis/clamp for motor.CATPart
mec/Robô/Final chassis/final chassis.CATProduct

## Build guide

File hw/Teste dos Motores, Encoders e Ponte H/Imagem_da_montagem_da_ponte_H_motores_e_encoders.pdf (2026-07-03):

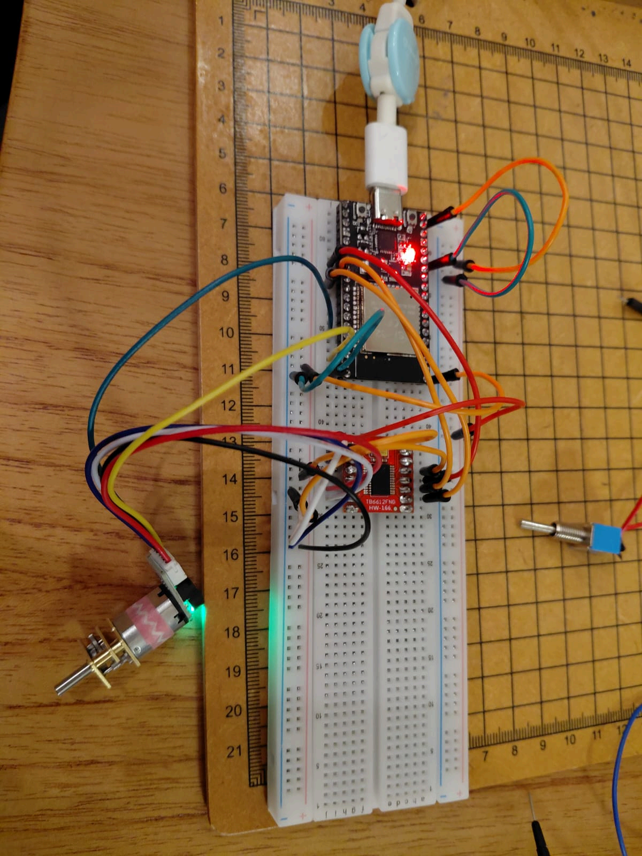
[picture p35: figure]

Figura 1 - Montagem da ponte H, motores e encoders.

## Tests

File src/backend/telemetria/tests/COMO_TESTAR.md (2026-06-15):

# Como testar a telemetria WebSocket

Valida a comunicação ESP32 → Backend via WebSocket e a persistência no SQLite.

---

## Pré-requisitos

```bash
# Na raiz do repositório
cd src/backend

# Instalar dependências (com venv ativo)
pip install -r requirements.txt
pip install websockets

# Criar as tabelas no banco
python manage.py migrate
```

---

## Passo 1 — Iniciar o servidor

```bash
daphne config.asgi:application
```

Saída esperada:

```
Listening on TCP address 127.0.0.1:8000
```

---

## Passo 2 — Rodar o simulador (outro terminal)

```bash
python telemetria/tests/simulador_ws.py
```

Saída esperada:
```
Conectando em ws://localhost:8000/ws/firmware/ ...
Conexão estabelecida.

  [OK] run_started — ack=1, corrida_id=<N>
  [OK] cell_discovered (0,0) dir=N — ack=2
  [OK] cell_discovered (1,0) dir=L — ack=3
  [OK] cell_discovered (2,0) dir=L — ack=4
  [OK] cell_discovered (3,0) dir=N — ack=5
  [OK] cell_discovered (3,1) dir=S — ack=6
  [OK] cell_discovered (2,1) dir=O — ack=7
  [OK] cell_discovered (1,1) dir=O — ack=8
  [OK] cell_discovered (0,1) dir=S — ack=9
  [OK] optimal_path_calculated — ack=10
  [OK] fast_run_started — ack=11
  [OK] run_finished — ack=12

Todos os eventos enviados com sucesso. corrida_id=<N>
```

Qualquer linha `[ERRO]` indica falha.

---

## Passo 3 — Verificar persistência no banco

```bash
python manage.py shell
```

```python
from telemetria.models import Corrida, Celula, EstadoAtual

c = Corrida.objects.last()
print("corrida_id      :", c.id)
print("finalizado_em   :", c.finalizado_em)    # deve ter data/hora
print("desafio_concluido:", c.desafio_concluido) # deve ser True
print("velocidade_med  :", c.velocidade_med)   # deve ser 0.31
print("consumo_bat     :", c.consumo_bat)       # deve ser 12.0 (100 - 88)
print("celulas         :", Celula.objects.filter(labirinto_id=c.labitinto_id).count())  # 8
print("estados         :", EstadoAtual.objects.filter(corrida_id=c).count())            # 8
```

Resultado esperado:
```
corrida_id      : <N>
finalizado_em   : 2026-...  (não nulo)
desafio_concluido: True
velocidade_med  : 0.31
consumo_bat     : 12.0
celulas         : 8
estados         : 8
```

---

## O que cada verificação prova

| Verificação | Critério de aceite |
|---|---|
| 12 ACKs recebidos | Backend processa todos os eventos do protocolo (CA-10-03) |
| `finalizado_em` preenchido | `run_finished` fecha a corrida no banco (CA-10-01) |
| `desafio_concluido = True` | Payload `sucesso` persistido corretamente |
| 8 células no banco | `cell_discovered` persiste cada célula com paredes (CA-10-02) |
| 8 estados no banco | `EstadoAtual` registra posição e bateria por evento |

---

## Rastreamento

- **US-10** — Comunicação em Tempo Real
- **CT-SW-01** — Sincronização de Telemetria
- **Issue #180** — Backend Core: WebSocket ESP32 → Backend

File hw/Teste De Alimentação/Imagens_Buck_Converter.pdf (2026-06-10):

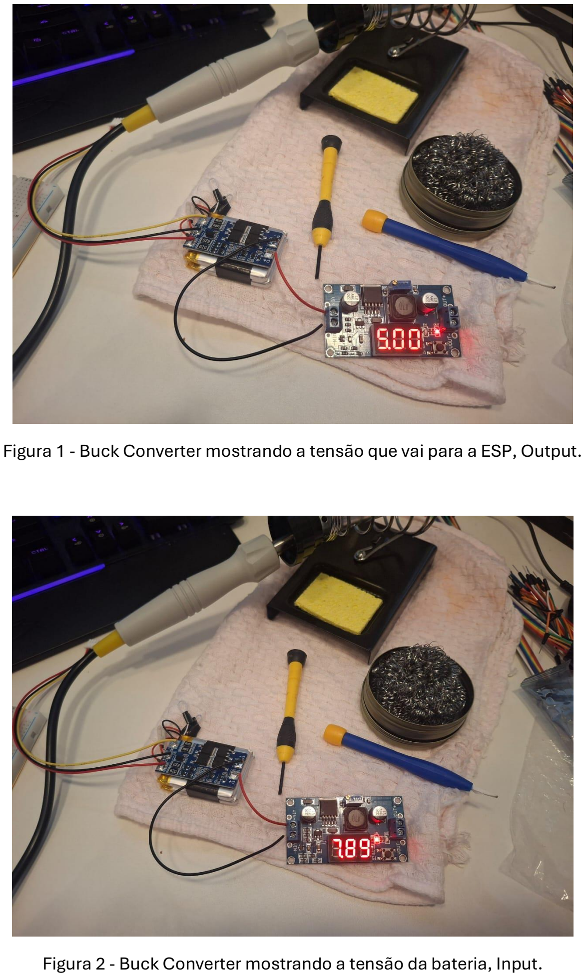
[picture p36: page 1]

Figura 1 - Buck Converter mostrando a tensão que vai para a ESP, Output.

Figura 2 - Buck Converter mostrando a tensão da bateria, Input.

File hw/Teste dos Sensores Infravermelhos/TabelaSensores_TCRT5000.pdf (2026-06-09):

Cm | Volts
1 | 0.14
2 | 0.19
3 | 0.24
4 | 1.31
5 | 1.82
6 | 2.04
7 | 2.24
8 | 2.40
9 | 2.55
10 | 2.65
11 | 2.72
12 | 2.76

Tabela Dos Sensores TCRT5000

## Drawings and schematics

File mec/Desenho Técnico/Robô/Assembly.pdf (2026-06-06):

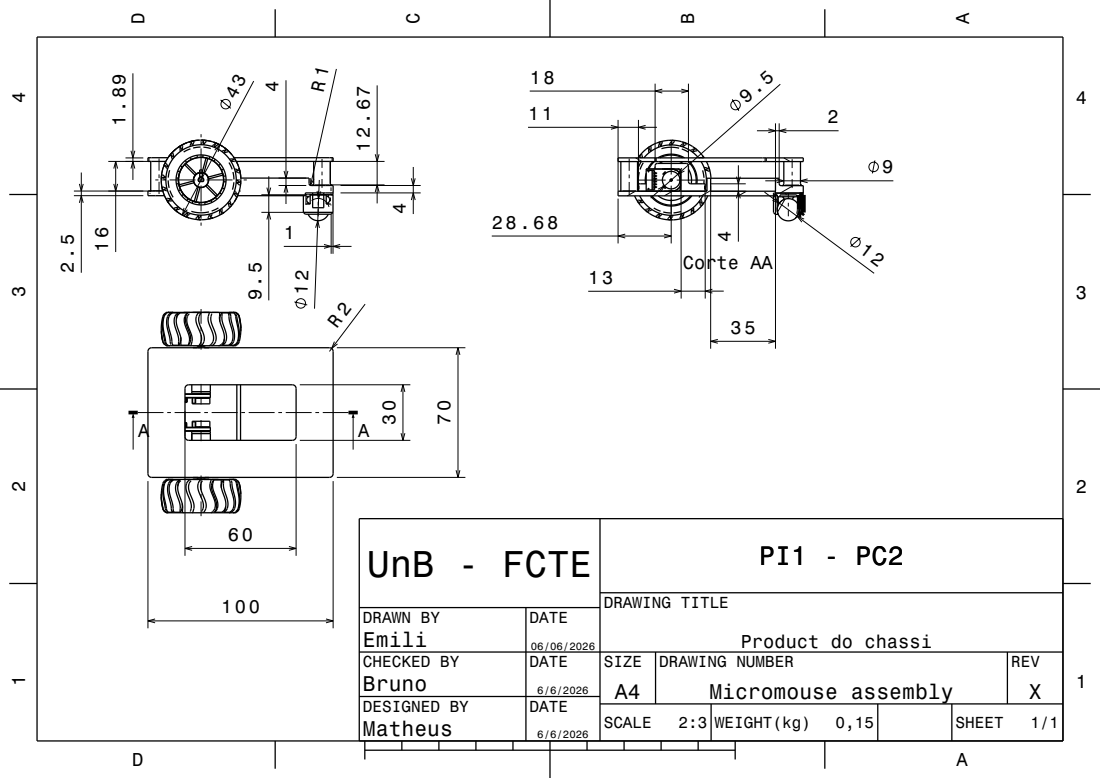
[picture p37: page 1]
DRAWING TITLE; PI1 - PC2 UnB - FCTE; Corte AA

DRAWN BY Emili | DATE 06/06/2026

Product do chassi

CHECKED BY Bruno | DATE 6/6/2026 | SIZE A4 | DRAWING NUMBER Micromouse assembly | REV X

DESIGNED BY Matheus | DATE 6/6/2026

SCALE 2:3 | WEIGHT(kg) 0,15 | SHEET 1/1

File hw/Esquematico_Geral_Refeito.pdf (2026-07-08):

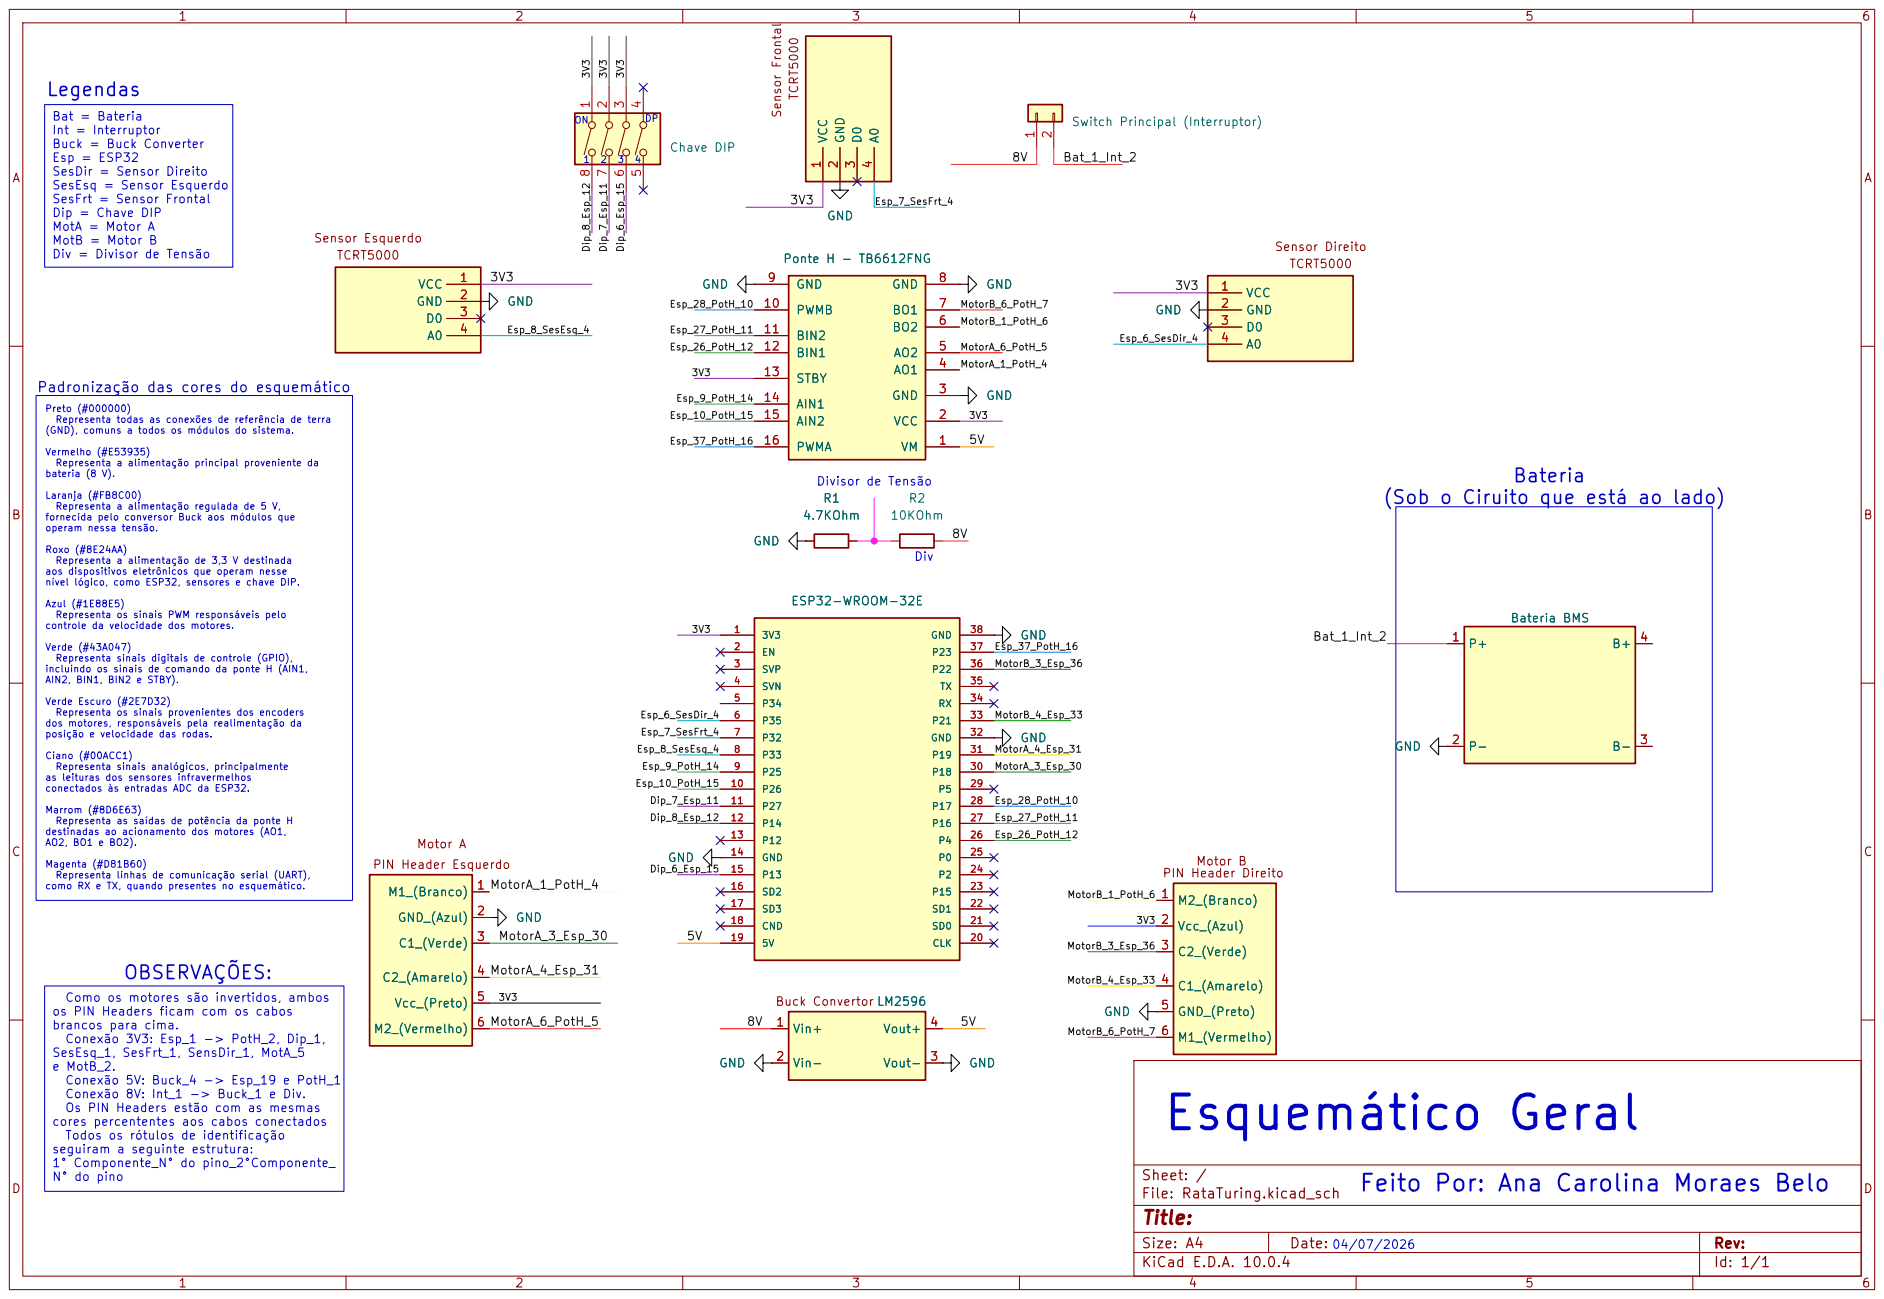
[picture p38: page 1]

3 ON OBSERVAÇÕES: Como os motores são invertidos, ambos os PIN Headers ficam com os cabos brancos para cima. Conexão 3V3: Esp_1 -> PotH_2, Dip_1,
Int = Interruptor Buck = Buck Converter Esp = ESP32

Switch Principal (Interruptor) GND

5 Chave DIP Motor A PIN Header Esquerdo

SesDir = Sensor Direito SesEsq = Sensor Esquerdo SesFrt = Sensor Frontal Dip = Chave DIP MotA = Motor A MotB = Motor B

Div Padronização das cores do esquemático

Preto (#000000) Representa todas as conexões de referência de terra

(GND), comuns a todos os módulos do sistema. Vermelho (#E53935) Representa a alimentação principal proveniente da bateria (8 V). Laranja (#FB8C00) Representa a alimentação regulada de 5 V,

(Sob o Ciruito que está ao lado)

fornecida pelo conversor Buck aos módulos que operam nessa tensão. Roxo (#8E24AA) Representa a alimentação de 3,3 V destinada aos dispositivos eletrônicos que operam nesse nível lógico, como ESP32, sensores e chave DIP. Azul (#1E88E5) Representa os sinais PWM responsáveis pelo controle da velocidade dos motores. Verde (#43A047) Representa sinais digitais de controle (GPIO),

incluindo os sinais de comando da ponte H (AIN1, AIN2, BIN1, BIN2 e STBY). Verde Escuro (#2E7D32) Representa os sinais provenientes dos encoders dos motores, responsáveis pela realimentação da posição e velocidade das rodas. Ciano (#00ACC1) Representa sinais analógicos, principalmente as leituras dos sensores infravermelhos conectados às entradas ADC da ESP32. Marrom (#8D6E63) Representa as saídas de potência da ponte H destinadas ao acionamento dos motores (AO1, AO2, BO1 e BO2). Magenta (#D81B60) Representa linhas de comunicação serial (UART), como RX e TX, quando presentes no esquemático.

PIN Header Direito Motor B M2_(Branco) 1

SesEsq_1, SesFrt_1, SensDir_1, MotA_5 e MotB_2. Conexão 5V: Buck_4 -> Esp_19 e PotH_1 Conexão 8V: Int_1 -> Buck_1 e Div. Os PIN Headers estão com as mesmas cores percententes aos cabos conectados

Todos os rótulos de identificação
seguiram a seguinte estrutura: 1° Componente_N° do pino_2°Componente_ N° do pino

Size: A4 | 04/07/2026 | Rev:
KiCad E.D.A. 10.0.4 | | Id: 1/1

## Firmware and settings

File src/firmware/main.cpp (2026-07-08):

#include <Arduino.h>
#include <cstring>
#include <array>
#include <algorithm>
#include <stdexcept>
#include "hal.h"
#include "motors.h"
#include "sensors.h"
#include "battery.h"
#include "ota.h"
#include "dip.h"

// seguindo a mesma lógica do código do simulador mms mas agora com funções declaradas e não apenas api do simulador
// os arrays sempre têm o tamanho do maior mapa suportado (8x8); quando o mapa é 4x4,
// só usamos a submatriz [0..3][0..3] e o resto fica sem uso.
constexpr int TAM_MAX = 8;
constexpr int MAX = 255;
constexpr char P_NORTE = 0x1;
constexpr char P_LESTE = 0x2;
constexpr char P_SUL   = 0x4;
constexpr char P_OESTE = 0x8;
enum class Direcao : int { norte = 0, leste = 1, sul = 2, oeste = 3};
constexpr int NUM_DIRECOES = 4;
constexpr int idx(Direcao d) { return static_cast<int>(d);}

class Micromouse {
public:
    // não lê as chaves DIP aqui: no boot os pinos ainda podem não estar
    // configurados (dip_init roda no setup()). O tamanho real do labirinto
    // só é definido quando reset() é chamado, logo antes de cada corrida.
    Micromouse() : tam(TAM_MAX) {}

    // reconfigura o labirinto lendo a chave DIP e zera a posição/memória.
    // deve ser chamado sempre antes de run(), assim o robô pode trocar
    // de mapa (4x4/8x8) entre uma corrida e outra sem precisar regravar o firmware.
    void reset() {
        selecionar_labirinto();
        pos_x  = 0;
        pos_y  = 0;
        direcao  = Direcao::norte;
        std::memset(paredes, 0, sizeof(paredes));
        inicializar_bordas();
    }

    void run() {
        detectar_paredes();
        calcular_distancias();
        ultima_checada = millis();
        while (!centro(pos_x, pos_y)) {
            detectar_paredes();
            calcular_distancias();
            melhor_celula();
            if (millis() - ultima_checada >= INTERVALO_BATERIA) {
            ultima_checada = millis();
            }
            ota_loop(); // mantém o servidor OTA respondendo mesmo durante a corrida
        }
        // chegou ao centro para os motores
        motors_parar();
    }

private:
    unsigned long ultima_checada = 0;
    const unsigned long INTERVALO_BATERIA = 30000;
    int  tam;   // tamanho do labirinto atual: 4 ou 8 (definido pela chave DIP)
    int  distancia[TAM_MAX][TAM_MAX];
    char paredes[TAM_MAX][TAM_MAX];
    int  pos_x, pos_y;
    Direcao direcao;
    static constexpr std::array<int, NUM_DIRECOES> move_x = {0, 1,  0, -1};
    static constexpr std::array<int, NUM_DIRECOES> move_y = {1, 0, -1, 0};
    static constexpr std::array<Direcao, NUM_DIRECOES> oposto = {Direcao::sul, Direcao::oeste, Direcao::norte, Direcao::leste
    };

    // lê as chaves DIP de mapa e decide o tamanho do labirinto (4x4 ou 8x8)
    void selecionar_labirinto() {
        if (mapa_4x4() && mapa_8x8()) {
            tam = 4;
        } else if (mapa_4x4()) {
            tam = 4;
        } else if (mapa_8x8()) {
            tam = 8;
        } else {
            tam = 8;
        }

    }

    void inicializar_bordas() {
        for (int i = 0; i < tam; i++) {
            paredes[i][tam - 1]  |= P_NORTE;
            paredes[i][0]  |= P_SUL;
            paredes[tam - 1][i] |= P_LESTE;
            paredes[0][i]  |= P_OESTE;
        }
    }

    bool centro(int x, int y) const {
        int c1 = tam / 2 - 1;
        int c2 = tam / 2;
        return (x == c1 || x == c2) && (y == c1 || y == c2);
    }

    bool tem_parede(int x, int y, Direcao d) const {
        return (paredes[x][y] & (1 << idx(d))) != 0;
    }

    void calcular_distancias() {
        for (int x = 0; x < tam; x++)
            for (int y = 0; y < tam; y++)
                distancia[x][y] = centro(x, y) ? 0 : MAX;
        bool alteracao = true;
        while (alteracao) {
            alteracao = false;
            for (int x = 0; x < tam; x++) {
                for (int y = 0; y < tam; y++) {
                    if (centro(x, y)) continue;

                    int melhor_vizinho = MAX;
                    auto verificar = [&](Direcao d, int nx, int ny) {
                        if (!tem_parede(x, y, d) && nx >= 0 && nx < tam && ny >= 0 && ny < tam)
                            melhor_vizinho = std::min(melhor_vizinho, distancia[nx][ny]);
                    };
                    verificar(Direcao::norte, x, y + 1);
                    verificar(Direcao::sul, x, y - 1);
                    verificar(Direcao::leste, x + 1, y);
                    verificar(Direcao::oeste, x - 1, y);

                    int nova = (melhor_vizinho == MAX) ? MAX : melhor_vizinho + 1;
                    if (nova < distancia[x][y]) {
                        distancia[x][y] = nova;
                        alteracao = true;
                    }
                }
            }
        }
    }
    // registra uma parede detectada na memória do labirinto
    void adicionar_parede(int x, int y, Direcao d) {
        paredes[x][y] |= (1 << idx(d));
        int nx = x + move_x[idx(d)];
        int ny = y + move_y[idx(d)];
        if (nx >= 0 && nx < tam && ny >= 0 && ny < tam)
            paredes[nx][ny] |= (1 << idx(oposto[idx(d)]));
    }

    Direcao relativa_para_absoluta(Direcao dir_mouse, int giro) const {
        return static_cast<Direcao>((idx(dir_mouse) + giro) % NUM_DIRECOES);
    }

    // detecção de paredes
    void detectar_paredes() {
        if (sensor_parede_frente())
            adicionar_parede(pos_x, pos_y, relativa_para_absoluta(direcao, 0));
        if (sensor_parede_direita())
            adicionar_parede(pos_x, pos_y, relativa_para_absoluta(direcao, 1));
        if (sensor_parede_esquerda())
            adicionar_parede(pos_x, pos_y, relativa_para_absoluta(direcao, 3));
    }

    // gira o robô com o mínimo de movimentos possível e avança uma célula.
    // os motores agora são de malha aberta (tempo fixo por comando)
    bool melhor_celula() {
        int melhor_direcao  = -1;
        int menor_distancia  = MAX + 1;

        for (int d = 0; d < NUM_DIRECOES; d++) {
            auto dir = static_cast<Direcao>(d);
            if (tem_parede(pos_x, pos_y, dir)) continue;
            int nx = pos_x + move_x[d];
            int ny = pos_y + move_y[d];
            if (nx < 0 || nx >= tam || ny < 0 || ny >= tam) continue;
            if (distancia[nx][ny] < menor_distancia) {
                menor_distancia = distancia[nx][ny];
                melhor_direcao  = d;
            }
        }

        if (melhor_direcao == -1) return false;

        int diferenca = (melhor_direcao - idx(direcao) + NUM_DIRECOES) % NUM_DIRECOES;
        switch (diferenca) {
            case 0:
                break; // já está de frente pra direção certa
            case 1:
                motors_girar_direita();
                break;
            case 2:
                motors_girar_tras();
                break;
            case 3:
                motors_girar_esquerda();
                break;
        }
        direcao = static_cast<Direcao>(melhor_direcao);

        motors_avancar_celula();
        pos_x += move_x[melhor_direcao];
        pos_y += move_y[melhor_direcao];
        return true;
    }
};

Micromouse mouse;
bool corrida_executada = false; // trava para não iniciar a corrida de novo enquanto START continuar ligada
String status_robo = "Aguardando chave START...";
int bateria_atual = 0;
void setup() {
    Serial.begin(115200);
    sensors_init();
    dip_init();
    battery_init();
    motors_init();
    ota_init();

   
}

void loop() {
    ota_loop();

    if (start() && !corrida_executada) {
        status_robo = "Chave ligada - Iniciando corrida!";
        delay(3000);
     
        mouse.reset(); // lê MAPA_4X4/MAPA_8X8 agora e prepara o labirinto do zero
        mouse.run();
        status_robo = "Corrida finalizada - Chegou ao centro!";
        corrida_executada = true; // trava até a chave START ser desligada
    }

    if (!start()) {
        corrida_executada = false; // rearma para permitir uma nova corrida
    }
}

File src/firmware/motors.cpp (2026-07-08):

#include "motors.h"
#include "sensors.h"
#include "hal.h"
#include <Arduino.h>

// esse código serve para controlar os dois motores do robô usando a ponte h e lendo o quanto eles andaram pelos encoders
// usando um pid pra tentar manter os dois girando na mesma velocidade

// aqui a gente guarda quantos pulsos cada roda já deu
// usamos volatile porque esses valores mudam o tempo todo no meio das interrupções
static volatile long enc_esq = 0;
static volatile long enc_dir = 0;

// essas duas funções são chamadas automaticamente toda vez que o encoder gira
// elas checam o outro pino pra saber se a roda tá indo pra frente ou pra trás e soma ou subtrai
static void IRAM_ATTR isr_enc_esq() {
    if (digitalRead(ENC_ESQ_B) == LOW)
        enc_esq++;
    else
        enc_esq--;
}
static void IRAM_ATTR isr_enc_dir() {
    if (digitalRead(ENC_DIR_B) == LOW)
        enc_dir--;
    else
        enc_dir++;
}
// aqui a gente liga os pinos pra fazer a roda esquerda ir pra frente ou pra trás
static void set_motor_esq(int pwm) {
    if (pwm >= 0) {
        digitalWrite(MOT_ESQ_INA1, HIGH);
        digitalWrite(MOT_ESQ_INA2, LOW);
    } else {
        digitalWrite(MOT_ESQ_INA1, LOW);
        digitalWrite(MOT_ESQ_INA2, HIGH);
        pwm = -pwm;
    }
    // manda a velocidade pro motor
    ledcWrite(MOT_ESQ_PWMA, constrain(pwm, 0, 255));
}


static void set_motor_dir(int pwm) {
    if (pwm >= 0) {
        digitalWrite(MOT_DIR_INB1, HIGH); 
        digitalWrite(MOT_DIR_INB2, LOW);
    } else {
        digitalWrite(MOT_DIR_INB1, LOW);
        digitalWrite(MOT_DIR_INB2, HIGH);
        pwm = -pwm;
    }
    ledcWrite(MOT_DIR_PWMB, constrain(pwm, 0, 255));
}

// configura todos os pinos de motor e encoder pra começarem a funcionar
void motors_init() {
    pinMode(MOT_ESQ_INA1, OUTPUT);
    pinMode(MOT_ESQ_INA2, OUTPUT);
    pinMode(MOT_DIR_INB1, OUTPUT);
    pinMode(MOT_DIR_INB2, OUTPUT);   

    // configura o pwm do esp32 pra gente poder controlar a velocidade
    ledcAttach(MOT_ESQ_PWMA, PWM_FREQ, PWM_BITS);
    ledcAttach(MOT_DIR_PWMB, PWM_FREQ, PWM_BITS);

    // pinos dos encoders entram como input pra gente ler o sinal deles
    pinMode(ENC_ESQ_A, INPUT_PULLUP);
    pinMode(ENC_ESQ_B, INPUT_PULLUP);
    pinMode(ENC_DIR_A, INPUT_PULLUP);
    pinMode(ENC_DIR_B, INPUT_PULLUP);

    // avisa o esp32 pra rodar aquelas funçoes de interrupção toda vez que o sinal do encoder subir
    attachInterrupt(digitalPinToInterrupt(ENC_ESQ_A), isr_enc_esq, RISING);
    attachInterrupt(digitalPinToInterrupt(ENC_DIR_A), isr_enc_dir, RISING);
}

// só zera a velocidade dos dois motores pra eles pararem
void motors_parar() {
    set_motor_esq(0);
    set_motor_dir(0);
    delay(DELAY_POS_MOVIMENTO_MS);   
}


static void mover(long alvo_esq, long alvo_dir, bool usar_sensor = false) {
    // desliga as interrupções rapidinho só pra zerar os contadores sem dar problema
    noInterrupts();
    enc_esq = 0;
    enc_dir = 0;
    interrupts();

    // vê pra qual lado cada roda tem que girar
    int sinal_esq = (alvo_esq >= 0) ? 1 : -1;
    int sinal_dir = (alvo_dir >= 0) ? 1 : -1;
    long abs_esq  = abs(alvo_esq);
    long abs_dir  = abs(alvo_dir);

    float erro_anterior = 0.0f;
    float integral      = 0.0f;

    // fica rodando aqui até as duas rodas chegarem no alvo
    while (true) {
        // le o quanto já andou
        noInterrupts();
        long lido_esq = enc_esq * sinal_esq;   // progresso sempre positivo
        long lido_dir = enc_dir * sinal_dir;
        interrupts();

        // checa se já chegou
        bool esq_ok = (lido_esq >= abs_esq);
        bool dir_ok = (lido_dir >= abs_dir);

        bool parede_proxima = usar_sensor && (sensor_cm(IR_FRENTE) < DIST_FRONTAL_LIMITE_CM); // para se o sensor lê menos que DIST_FRONTAL_LIMITE_CM (3 cm),
        if ((esq_ok && dir_ok) || parede_proxima) break;

        // aqui a gente calcula o erro do pid
        // ve qual roda tá mais adiantada comparando a porcentagem do que elas já andaram
        float prog_esq = (abs_esq > 0) ? (float)lido_esq / abs_esq : 1.0f;
        float prog_dir = (abs_dir > 0) ? (float)lido_dir / abs_dir : 1.0f;
        float erro     = prog_esq - prog_dir;   // se der positivo a esquerda ta mais rapida

        integral      += erro;
        float derivada = erro - erro_anterior;
        erro_anterior  = erro;

        // faz a conta do pid misturando as constantes que a gente definiu
        float correcao = PID_KP * erro + PID_KI * integral + PID_KD * derivada;

        // se a roda já chegou no alvo ela para, senão a gente soma ou subtrai a correção da velocidade base
        int pwm_esq = esq_ok ? 0 : (int)(VEL_BASE - correcao * 50);
        int pwm_dir = dir_ok ? 0 : (int)(VEL_BASE + correcao * 50);

        
        set_motor_esq(constrain(pwm_esq, 0, VEL_MAX) * sinal_esq);
        set_motor_dir(constrain(pwm_dir, 0, VEL_MAX) * sinal_dir);
        delay(2);   
    }

 
    motors_parar();
    delay(80);   
}

void motors_avancar_celula() {
    const int vel_base = 100;

    digitalWrite(MOT_ESQ_INA1, HIGH);
    digitalWrite(MOT_ESQ_INA2, LOW);
    digitalWrite(MOT_DIR_INB1, LOW);
    digitalWrite(MOT_DIR_INB2, HIGH);
    ledcWrite(MOT_DIR_PWMA, vel_base);
    ledcWrite(MOT_DIR_PWMB, vel_base);
    delay (700);
    ledcWrite(MOT_ESQ_PWMA, 0); 
    ledcWrite(MOT_DIR_PWMB, 0);
    delay(DELAY_POS_MOVIMENTO_MS);   
}

void motors_girar_direita() {
    int vel_teste = 150;
    digitalWrite(MOT_ESQ_INA1, LOW);
    digitalWrite(MOT_ESQ_INA2, HIGH);
    digitalWrite(MOT_DIR_INB1, HIGH);
    digitalWrite(MOT_DIR_INB2, LOW);
    ledcWrite(MOT_ESQ_PWMA, vel_teste);
    ledcWrite(MOT_DIR_PWMB, vel_teste);
    delay(288);
    ledcWrite(MOT_ESQ_PWMA, 0);
    ledcWrite(MOT_DIR_PWMB, 0);
    delay(DELAY_POS_MOVIMENTO_MS);   
}

// gira 270 graus no proprio eixo pra direita
void motors_girar_esquerda() {
    int vel_teste = 150;
    digitalWrite(MOT_ESQ_INA1, LOW);
    digitalWrite(MOT_ESQ_INA2, HIGH);
    ledcWrite(MOT_ESQ_PWMA, vel_teste);
    digitalWrite(MOT_DIR_INB1, HIGH);
    digitalWrite(MOT_DIR_INB2, LOW);
    ledcWrite(MOT_DIR_PWMB, vel_teste);
    delay(870);
    ledcWrite(MOT_ESQ_PWMA, 0); 
    ledcWrite(MOT_DIR_PWMB, 0);
    delay(DELAY_POS_MOVIMENTO_MS);   
}

void motors_girar_tras() {
    int vel_teste = 150;
    digitalWrite(MOT_ESQ_INA1, LOW);
    digitalWrite(MOT_ESQ_INA2, HIGH);
    ledcWrite(MOT_ESQ_PWMA, vel_teste);
    digitalWrite(MOT_DIR_INB1, HIGH);
    digitalWrite(MOT_DIR_INB2, LOW);
    ledcWrite(MOT_DIR_PWMB, vel_teste);
    delay(585);
    ledcWrite(MOT_ESQ_PWMA, 0);
    ledcWrite(MOT_DIR_PWMB, 0);
    delay(DELAY_POS_MOVIMENTO_MS);   
}

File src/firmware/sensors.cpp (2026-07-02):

#include "sensors.h"
#include "hal.h"
#include <Arduino.h>

// Tabela de calibração TCRT5000: tensão (V) por distância (cm), de 1cm a 12cm
static const float tabela_v[] = {0.14, 0.19, 0.24, 1.31, 1.82, 2.04, 2.24, 2.40, 2.55, 2.65, 2.72, 2.76};

void sensors_init() {
    pinMode(IR_FRENTE,   INPUT);
    pinMode(IR_ESQUERDA, INPUT);
    pinMode(IR_DIREITA,  INPUT);
}

static int ler_sensor(int pino) {
    int soma = 0;
    for (int i = 0; i < 4; i++) soma += analogRead(pino);
    return soma / 4;
}

// converte leitura ADC para tensão em volts
float sensor_volts(int pino) {
    return (ler_sensor(pino) / 4095.0f) * 3.3f;
}

// estima distância real em cm (interpolação na tabela + correção de offset)
float sensor_cm(int pino) {
    float v = sensor_volts(pino);
    if (v <= tabela_v[0])  return 1.0f;
    if (v >= tabela_v[11]) return 12.0f + SENSOR_OFFSET_CM;
    for (int i = 0; i < 11; i++) {
        if (v >= tabela_v[i] && v <= tabela_v[i + 1]) {
            float frac = (v - tabela_v[i]) / (tabela_v[i + 1] - tabela_v[i]);
            return (i + 1) + frac + SENSOR_OFFSET_CM;
        }
    }
    return -1.0f;
}

// retorna true se há parede na frente — robô está no centro da célula, pronto para girar
bool sensor_parede_frente() {
    return sensor_cm(IR_FRENTE) < DIST_FRONTAL_LIMITE_CM;
}

// retorna true se há parede na direita
bool sensor_parede_direita() {
    return sensor_cm(IR_DIREITA) < DIST_SEM_PAREDE_CM;
}

// retorna true se há parede na esquerda
bool sensor_parede_esquerda() {
    return sensor_cm(IR_ESQUERDA) < DIST_SEM_PAREDE_CM;
}

// Erro lateral em cm para uso no PID de alinhamento:
//   positivo → robô desviado para a direita → corrigir virando à esquerda
//   negativo → robô desviado para a esquerda → corrigir virando à direita
//   zero     → sem paredes laterais detectadas, sem referência
float sensor_erro_lateral() {
    float esq = sensor_cm(IR_ESQUERDA);
    float dir = sensor_cm(IR_DIREITA);
    bool tem_esq = (esq < DIST_SEM_PAREDE_CM);
    bool tem_dir = (dir < DIST_SEM_PAREDE_CM);

    if (tem_esq && tem_dir) return esq - dir;
    if (tem_esq)            return esq - DIST_LATERAL_ALVO_CM;
    if (tem_dir)            return DIST_LATERAL_ALVO_CM - dir;
    return 0.0f;
}

// retorna true se o desvio lateral supera a margem e precisa de correção
bool sensor_precisa_corrigir() {
    return fabsf(sensor_erro_lateral()) > DIST_LATERAL_MARGEM_CM;
}

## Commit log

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2026-05-10 Arquivos de impressão 3D
    [1st level.stl, 2nd level.stl, Clamp for N20 Motor.stl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]
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2026-05-18 Adicionar CAD Labirinto
    [Base (chapa).CATPart, Labirinto Assembly.CATProduct, Pilar de Encaixe.CATPart]
2026-05-19 chore: alterando o gitignore para parar de rastrear arquivos desnecessários do python e django
2026-05-19 adiciona axios pra comunicação de com api, resolução melhorada de visual de dashboars
2026-05-20 feat: criado o header do labirinto com banco de dados estaticos, seguindo o figma
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2026-05-20 Add files via upload
    Docs que a equipe de eletronica usa para se organizar
2026-05-26 Esqueleto do algoritmo de busca (flood fill)
    Para testar o algoritmo são necessárias duas coisas principais.
    Primeiro o software chamado mms, pode ser encontrado no github e depois dar um comando de build na api.c e no arquivo mouse.c depois só colocar no run command o caminho do executável e pronto. Caso e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
2026-05-26 feat: criação da rota /api/labirintos com métodos de post e get (#63)
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2026-05-27 fix:modificações no gitignore e commit de dependencias
2026-05-28 CAD chassis
    [1st level.CATPart, 2nd level.CATPart, Calota.CATPart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]
2026-05-28 pilar stl
    [Pilar de Encaixe.stl]
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2026-06-03 codigos do micromouse desenvolvidos
    Os arquivos .h são para definir pinos e chamadas para main. Em sensors.cpp temos como os sensores vão ler e como a lógica funciona para deteccão de paredes. Em motors.cpp temos tudo relacionado aos m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
2026-06-04 Add files via upload
    Soldei fios para conectar o Buck Converter na bateria LiPo e ajustei o poteciometro interno ate que a tensao de saida fosse 5V para alimentar a ESP32. Os detalhes estao no esquematico que desenhei e 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
2026-06-05 docs: adiciona diagrama de atividades
    Adicionado diagrama de atividades para documentar o fluxo principal do sistema e apoiar a compreensão dos processos modelados.
2026-06-05 docs: atualiza documentação do backlog
    Documenta o backlog do produto de software, incluindo épicos, histórias de usuário e requisitos não funcionais para o sistema de monitoramento e navegação autônoma do Micromouse.
2026-06-05 feat: implementa renderização de lçabirinto, termina dashboard, começa o desenvolvimento de historico, esperando implementação de webSocket
2026-06-05 docs: adiciona roteiro de testes funcionais
    Adiciona a documentação do roteiro de testes funcionais, incluindo introdução, casos de teste, critérios de validação e rastreabilidade com as histórias de usuário do projeto.
2026-06-06 Changes in the chassis
    [Ball Caster 12mm.CATProduct, Housing.CATPart, Hub.CATPart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]
2026-06-06 Mudanças no chassi
    [Calota.CATPart, Roda.CATPart, calota_roda.CATProduct]
2026-06-06 Adicionando função de porcentagem da bateria
    Através de um divisor de tensão vai ser possível lermos a quantidade restante da bateria
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2026-06-06 Mudança de nome da pasta
    [1st level.CATPart, 2nd level.CATPart, Ball Caster 12mm.CATProduct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]
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2026-06-07 Uploading DatasheetCP2102-9
    Devido a um errp que ocorreu anteriormente, fiz o upload manual.
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2026-06-07 Criando diretório
    Criando diretório com melhor nomenclatura para que possa abranger de forma mais precisa os arquivos presentes dentro dele.
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2026-06-07 Delete hw/Projeto Conceitual de Eletrônica ED1/Captura de tela 2026-05-18 201925.png
    O print foi substituido pelo pdf.
2026-06-07 Delete hw/Projeto Conceitual de Eletrônica ED1/Captura de tela 2026-05-18 202034.png
    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
2026-06-07 Delete hw/Projeto Conceitual de Eletrônica ED1/Captura de tela 2026-05-18 202042.png
    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
2026-06-07 Delete hw/Requisitos de Eletrônica/Captura de tela 2026-05-18 205330.png
    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
2026-06-07 Delete hw/Teste dos Sensores Infravermelhos/esquematico_dos_sensores.jpeg
    O print foi substituido por um arquivo digital.
2026-06-07 Delete hw/Update na Lógica de Alimentação/esquematico_switch_mestre.jpeg
    O print foi substituido pelo arquivo digital.
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2026-06-07 Esquemático do Divisor de Tensão
    Esquemático em formato digital do divisor de tensão para melhor ilustração do mesmo.
2026-06-07 Tabela Dos Sensores TCRT5000
    Tabela Dos Sensores TCRT5000 de modo digital no formato pdf.
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2026-06-07 Esquemático dos Motores E Da Ponte H
    Esquemático dos Motores E Da Ponte H digitalizado e em formato pdf.
2026-06-07 Delete hw/BOM_PI1_MICROMOUSE.xlsx
    O arquivo BOM já foi adicionado no formato pdf no seguinte caminho: " hw/Componentes "
    [BOM_PI1_MICROMOUSE.xlsx]
2026-06-07 Delete hw/Divisor de Tensão/esquematico_divisor_de_tensao.jpeg
    O Esquemático do dividor de tensão digital já foi adicionado.
2026-06-07 Imagens do Divisor de Tensão
    Pdf contendo as imagens do divisor de tensão.
2026-06-07 Delete hw/Teste dos Sensores Infravermelhos/tabela_sensores_volts_cm.jpeg
    Arquivo não é mais necessário pois foi feito um arquivo digital que já está presente no diretório.
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2026-06-09 feat: integra back com o front, recebimento de dados ok, problema no maze canvas
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2026-06-10 chore: remove arquivos hw reorganizados e alinha com main
    [BOM_PI1_MICROMOUSE.xlsx]
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2026-06-15 docs: no pages corrige documentos de software, corrige caminho de imagens, adiciona documentos de estruturas e hardware
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2026-06-21 fix:consertando o consurmers para sempre ativo
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2026-06-27 Simplify battery voltage reading logic
    Refactor battery voltage reading to simplify ADC noise reduction and calculation.
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2026-07-07 fix/ arruma bug de contagem de celulas visitadas
2026-07-07 fix: corrige de verdade numero de celulas visitadas, tanto vindo de uma corrida imediata ou de reload na pagina
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
